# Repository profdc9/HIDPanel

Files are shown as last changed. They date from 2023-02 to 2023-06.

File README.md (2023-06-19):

# HIDPanel

This is a customizable HID controller for game panels.  The HIDPanel has positions for up to 15 plug in control modules.  These modules can be single buttons, button pairs, rotary encoders, rotary potentiometers, slide potentiometers, and dual axis joysticks (PS4 or Xbox One type replacement joysticks).

The device appears as a USB CDC serial port, a USB HID keyboard, and a USB HID gamepad.  The actions of each module is configured through the serial port.  A command string configures the Keyboard or Gamepad controls to be triggered in response to each action.

# Commands

The commands are sent via the USB CDC serial port terminated by the enter character.  Here are the commands:

SET &lt;module number&gt; &lt;action number&gt; &lt;action command string&gt;

Sets the action command string corresponding to the action number for the given module number (1 to 15).

SHOW &lt;module number&gt;

Shows the current command strings for the module number.  If the module number is zero, show the action strings for all of the modules.

WRITE

Writes the current configuration to flash memory to be restored on power up.

HELP

Display the help (the list of commands).

# Module inputs

Each module has three inputs.  Switch 1, which is a digital only input, switch 2, which is digital or analog, and an analog input, which can be used as a digital or analog input.

The action numbers are:

- 100: Button 1 Pressed (grounded)
- 101: Button 1 Released (high)
- 200: Button 2 Pressed (grounded)
- 201: Button 2 Released (high)
- 300: Analog axis pressed (grounded)
- 301: Analog axis released (high)
- 302: Analog axis moved
- 311: Analog axis position 1/9 (left most)
- 312: Analog axis position 2/9
- 313: Analog axis position 3/9
- 314: Analog axis position 4/9
- 315: Analog axis position 5/9 (center) 
- 316: Analog axis position 6/9
- 317: Analog axis position 7/9
- 318: Analog axis position 8/9
- 319: Analog axis position 9/9 (right most)
- 400: Rotary encoder left
- 401: Rotary encoder right

# Command string

The command string is a sequence of one or two character codes separated by commas.  It should not contain any spaces.  There are three modes.  The mode needs to be selected before the commands for the mode are used.  Multiple modes may be used in the command string by switching between them.  The default is keyboard mode.

- LD: LED Mode
  - Hx: Turn on LED x (x = 1 to 4)
  - Lx: Turn off LED x (x = 1 to 4)
- GP: Gamepad Mode
  - Gx: Set axis x to analog input (x = 1-6, 1=left stick x, 2=left stick y, 3=left stick z, 4=right stick x, 5=right stick y, 6=right stick z)
  - Nx: Set axis x to analog input but reverse the axis
  - Zx: Set axis x to switch 2 analog input
  - Yx: Set axis x to switch 2 analog input but reverse the axis
  - Dx: Set Dpad input to value x (x = 0-8, 0=Centered, 1=Up, 2=Up Right, 3=Right, 4=Down Right, 5=Down, 6=Down Left, 7=Left, 8=Up Left)
  - Hx: Press button x (x=1 to 32)
  - Lx: Release button x
- KB: Keyboard Mode
  - Blank (zero length): keyboard release (two consective commas).
  - LC: Select left control for next key
  - LS: Select left shift for next key
  - LA: Select left alt for next key
  - LG: Select left gui for next key
  - RC: Select right control for next key
  - RS: Select right shift for next key
  - RA: Select right alt for next key
  - RG: Select right gui for next key
  - NK: No key 
  - A-Z: Press key A to Z
  - 0-9: Press key 0 to 9
  - EN: Enter
  - ES: Escape
  - BK: Backspace
  - TB: Tab
  - SP: Space bar
  - -: Minus key
  - =: Equal key
  - [: Left bracket
  - ]: Right bracket
  - \\: Backslash
  - E1: Europe 1
  - E2: Europe 2
  - ; : Semicolon
  - ` : Grave
  - CM: Comma
  - .: Period
  - /: Slash
  - CC: Caps Lock
  - F1-F9: F1 to F9
  - FA: F10 key
  - FB: F11 key
  - FC: F12 Key
  - PS: Print Screen
  - SL: Scroll Lock
  - PA: Pause
  - IN: Insert 
  - HO: Home
  - PU: Page Up
  - DE: Delete
  - ED: End
  - PD: Page Down
  - AR: Arrow Right
  - AL: Arrow Left
  - AD: Arrow Down
  - AU: Arrow Up
  - NL: Num Lock
  - KD: Keypad Divide
  - KM: Keypad Multiple
  - KS: Keypad Subtract
  - KA: Keypad Add
  - KE: Keypad Enter
  - K0-K9: Keypad 0 to 9
  - KL: Keypad Decimal Point
  - KQ: Keypad Equal

Examples:

- KB,LS,H,,E,,L,,L,,O,, : Type the word "HELLO" with the left shift key pressed down during "H" (to capitalize it).
- GP,G2 : Take the analog value of the module and set it to the left stick Y axis.
- GP,D1,D0,D1,D0,D5,D0,D5,D0,D7,D0,D3,D0,D3,D0,H2,L2,H1,L1 : Do combination up,up,down,down,left,right,left,right (on DPad), and then press and release button 2 and then button 1.
- GP,H1,LD,H2 : press button 1, light up LED 2
- KB,F1,GP,H1,LD,L3,GP,L1 : Press keyboard key F1, press button 1 on gamepad, turn off LED 3, release button 1 on gamepad.  Button F1 remains pressed.

Complete commands:

- SET 1 100 KB,A,, : when button 1 on module 1 is pressed, press down the A key
- SET 1 101 KB,, : when button 1 on module 1 is release, release any key
- SET 11 302 GP,G1 : set analog axis of module 11 to axis 1 of the gamepad
- SET 15 302 GP,G2 : set analog axis of module 15 to axis 2 of the gamepad
- SET 11 302 GP,N1 : set analog axis of module 11 to axis 1 of the gamepad, but invert the input
- SET 15 302 GP,N2 : set analog axis of module 15 to axis 2 of the gamepad, but invert the input
- SET 11 100,GP,H4 : when analog stick button is pushed in, press button 4 on gamepad
- SET 11 101,GP,L4 : when analog stick button is released, depress button 4 on gamepad

Pictures:

The following is a pciture of the HIDPanel with different controls in it.  In module 1 is a single push button. In module 3 is a rotary potentiometer, In module 4 is a slide switch.  In module 6 is a rotary encoder.  In module 8 is a push-on push-off button.  Modules 9 and 13 have a digital gamepad.  Modules 10 and 14 have a slide potentiometer.  Modules 11 and 15 have a dual axis joystick.

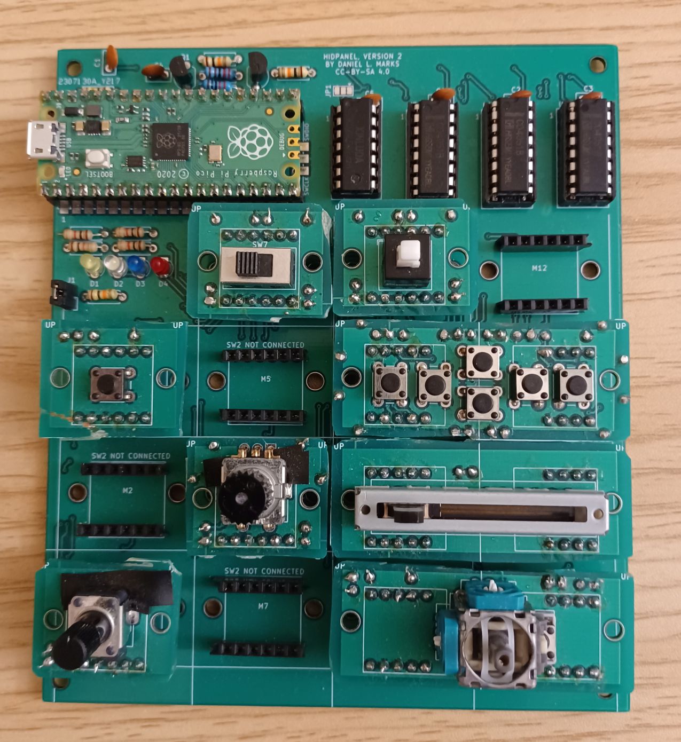
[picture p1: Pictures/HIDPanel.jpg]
HIDPanel


This is the 3-d printed cover that goes over the HIDPanel.  It is a parametric FreeCAD model and the port openings can be customized in FreeCAD before outputting the cover for the particular modules used.

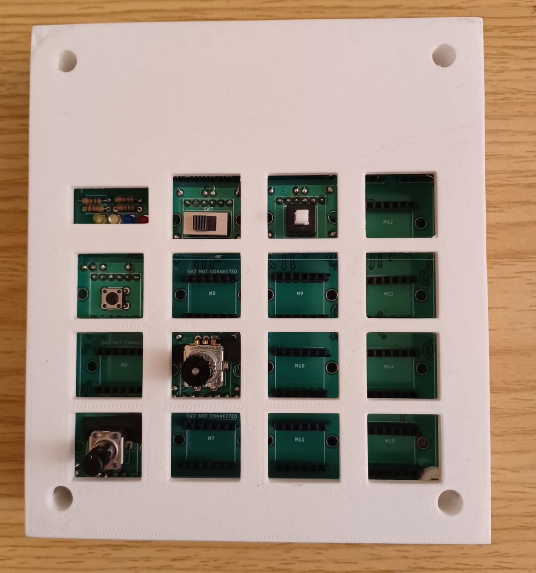
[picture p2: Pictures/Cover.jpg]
Cover


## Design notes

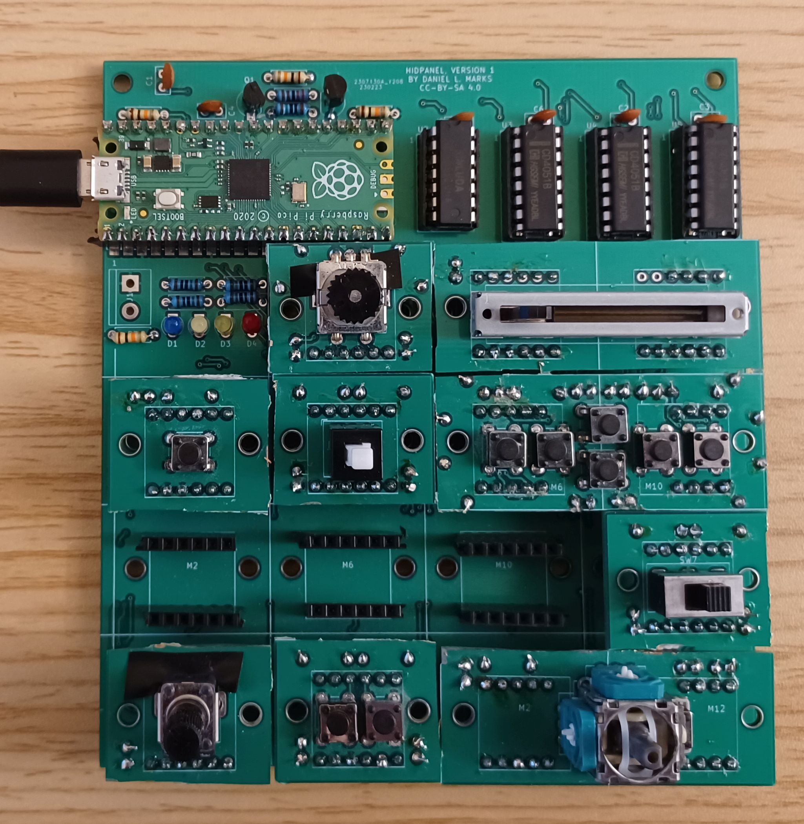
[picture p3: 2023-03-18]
Pictures/pic2.jpg

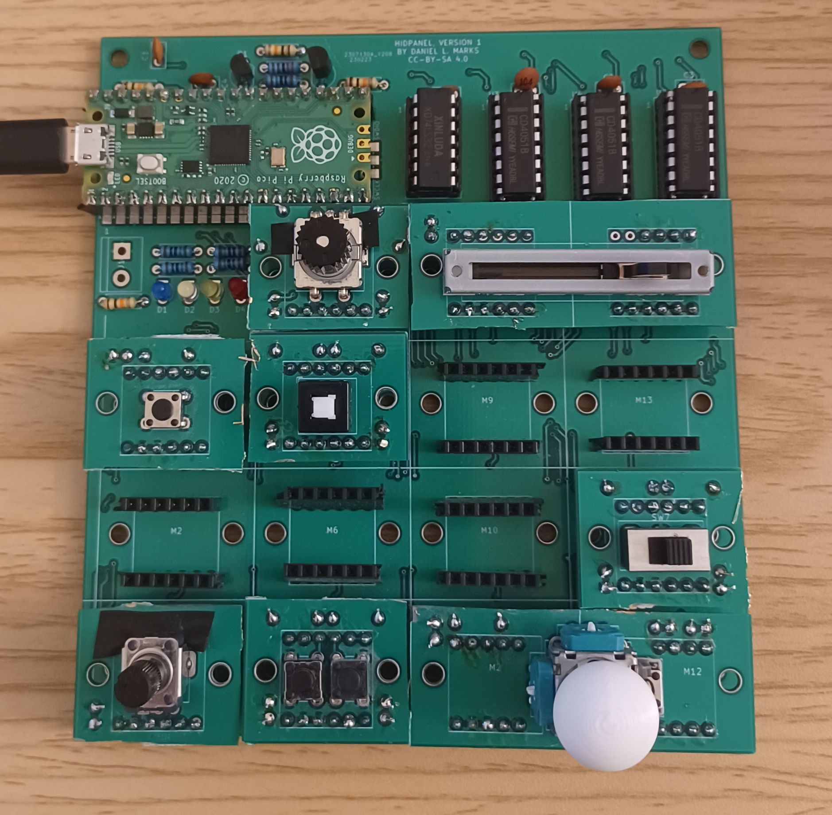
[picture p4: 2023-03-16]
Pictures/pic1.jpg

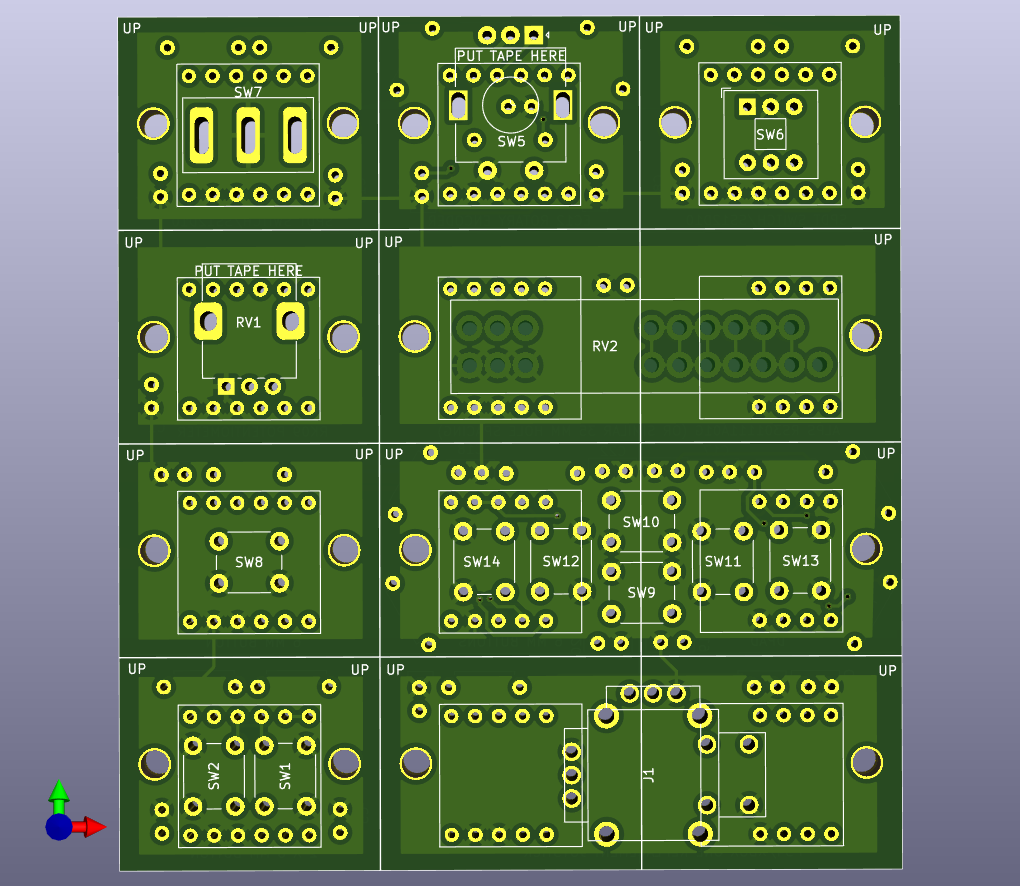
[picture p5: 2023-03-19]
HIDControls/HIDControls.png

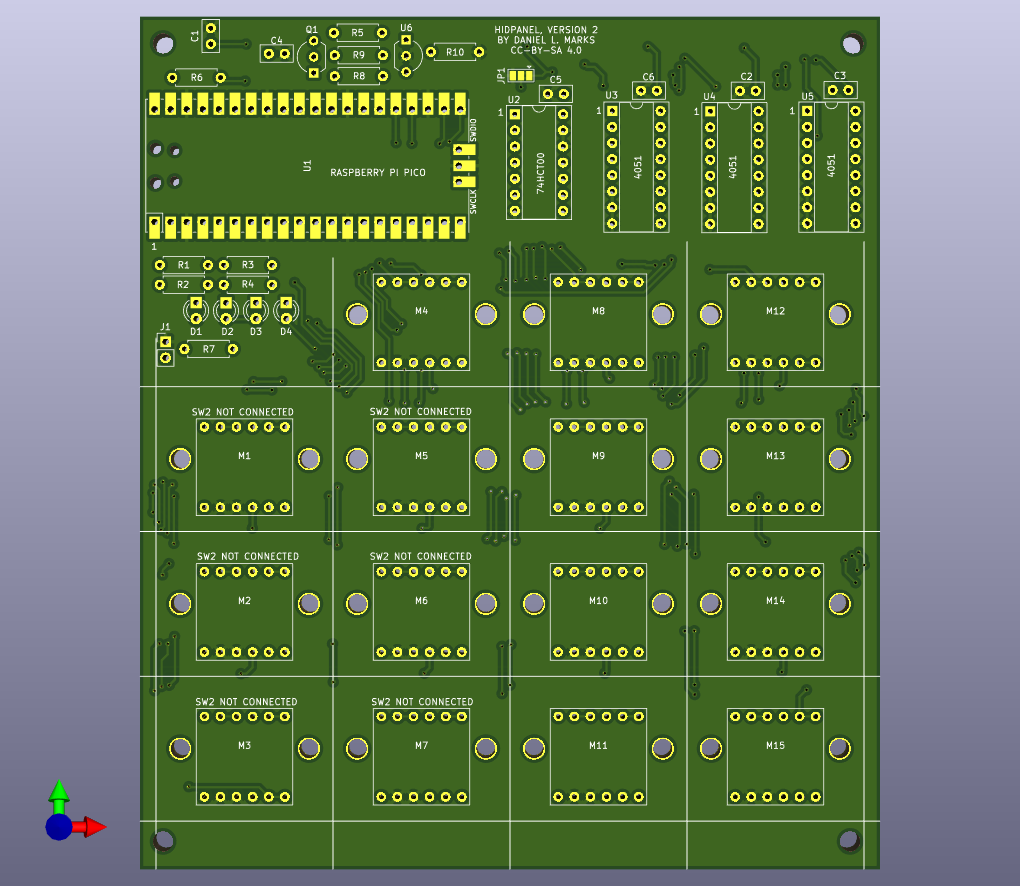
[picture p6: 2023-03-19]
HIDPanel/HIDPanel.png

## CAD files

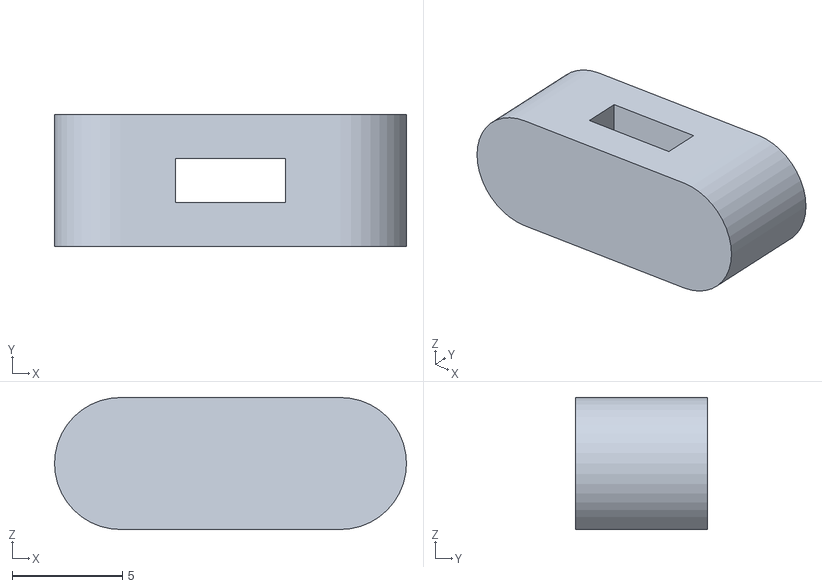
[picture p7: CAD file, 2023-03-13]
CAD/SlideLeft-SlideTotal.stl
16.0 x 6.00 x 6.00

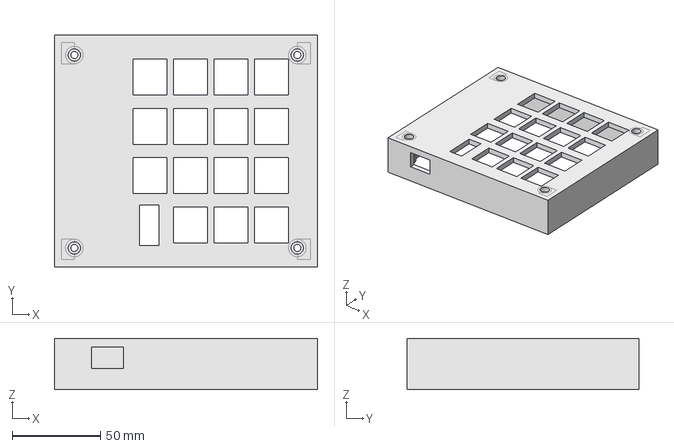
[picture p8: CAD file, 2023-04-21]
CAD/HIDPanelCover.FCStd
148.6 x 130.8 x 29.0 mm

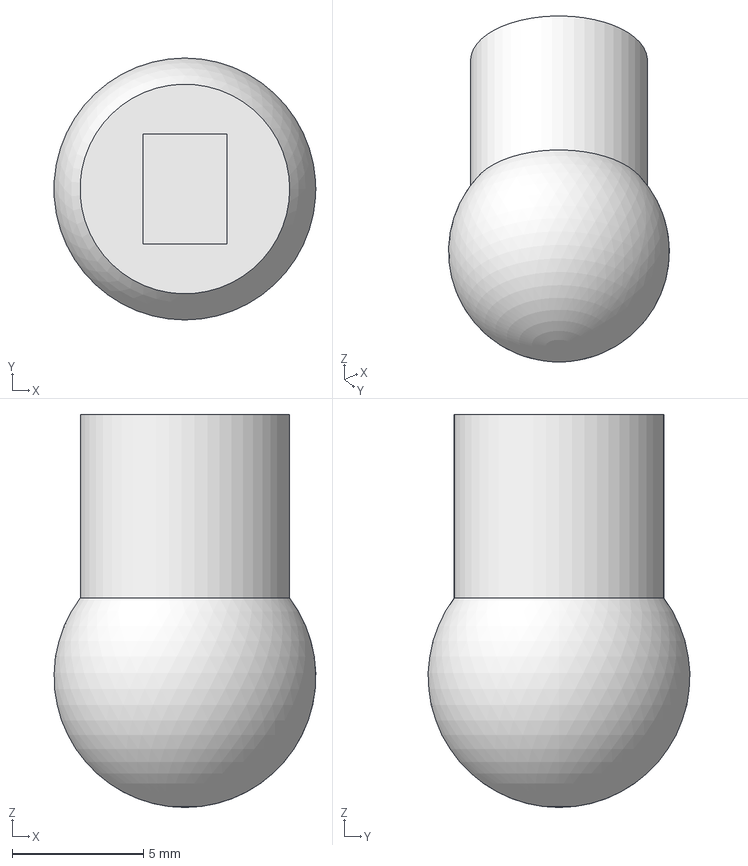
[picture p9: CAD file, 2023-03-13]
CAD/StickEnd.FCStd
9.99 x 10.00 x 15.0 mm

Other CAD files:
CAD/StickEnd-StickTotal.stl
CAD/HIDPanelCover-BoxWithStandOffs.stl
CAD/SlideLeft.FCStd

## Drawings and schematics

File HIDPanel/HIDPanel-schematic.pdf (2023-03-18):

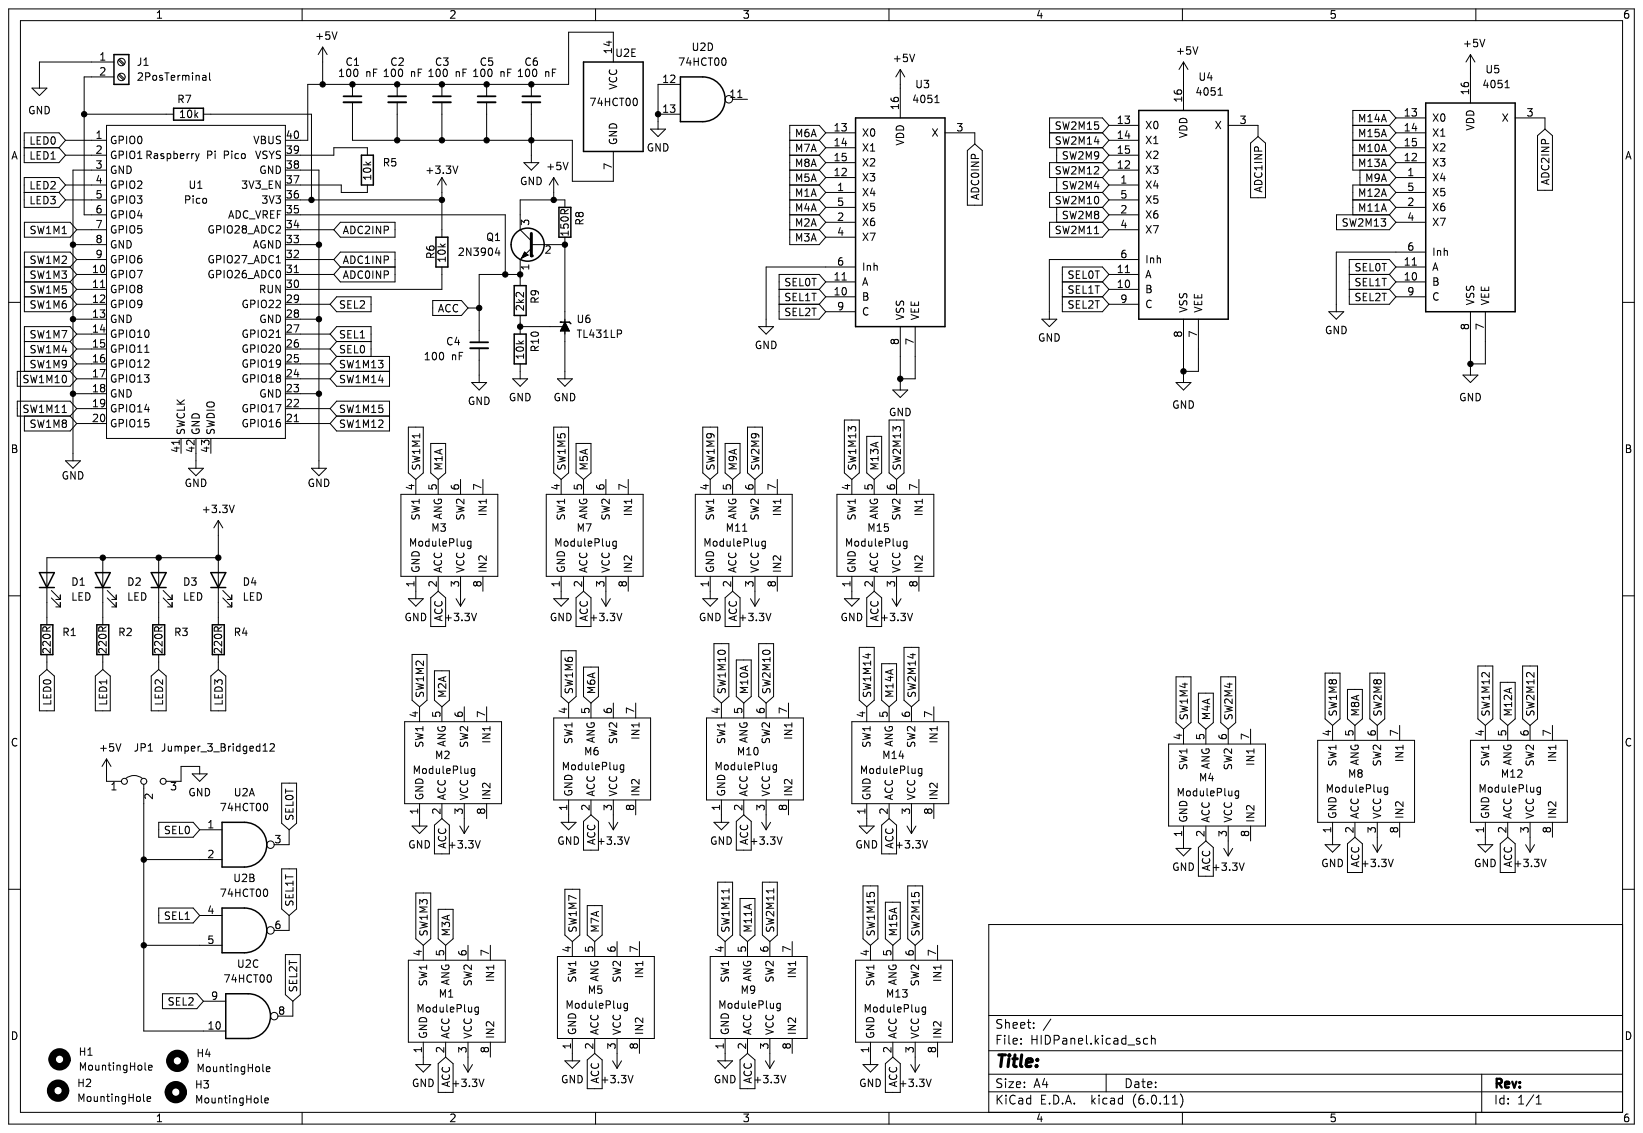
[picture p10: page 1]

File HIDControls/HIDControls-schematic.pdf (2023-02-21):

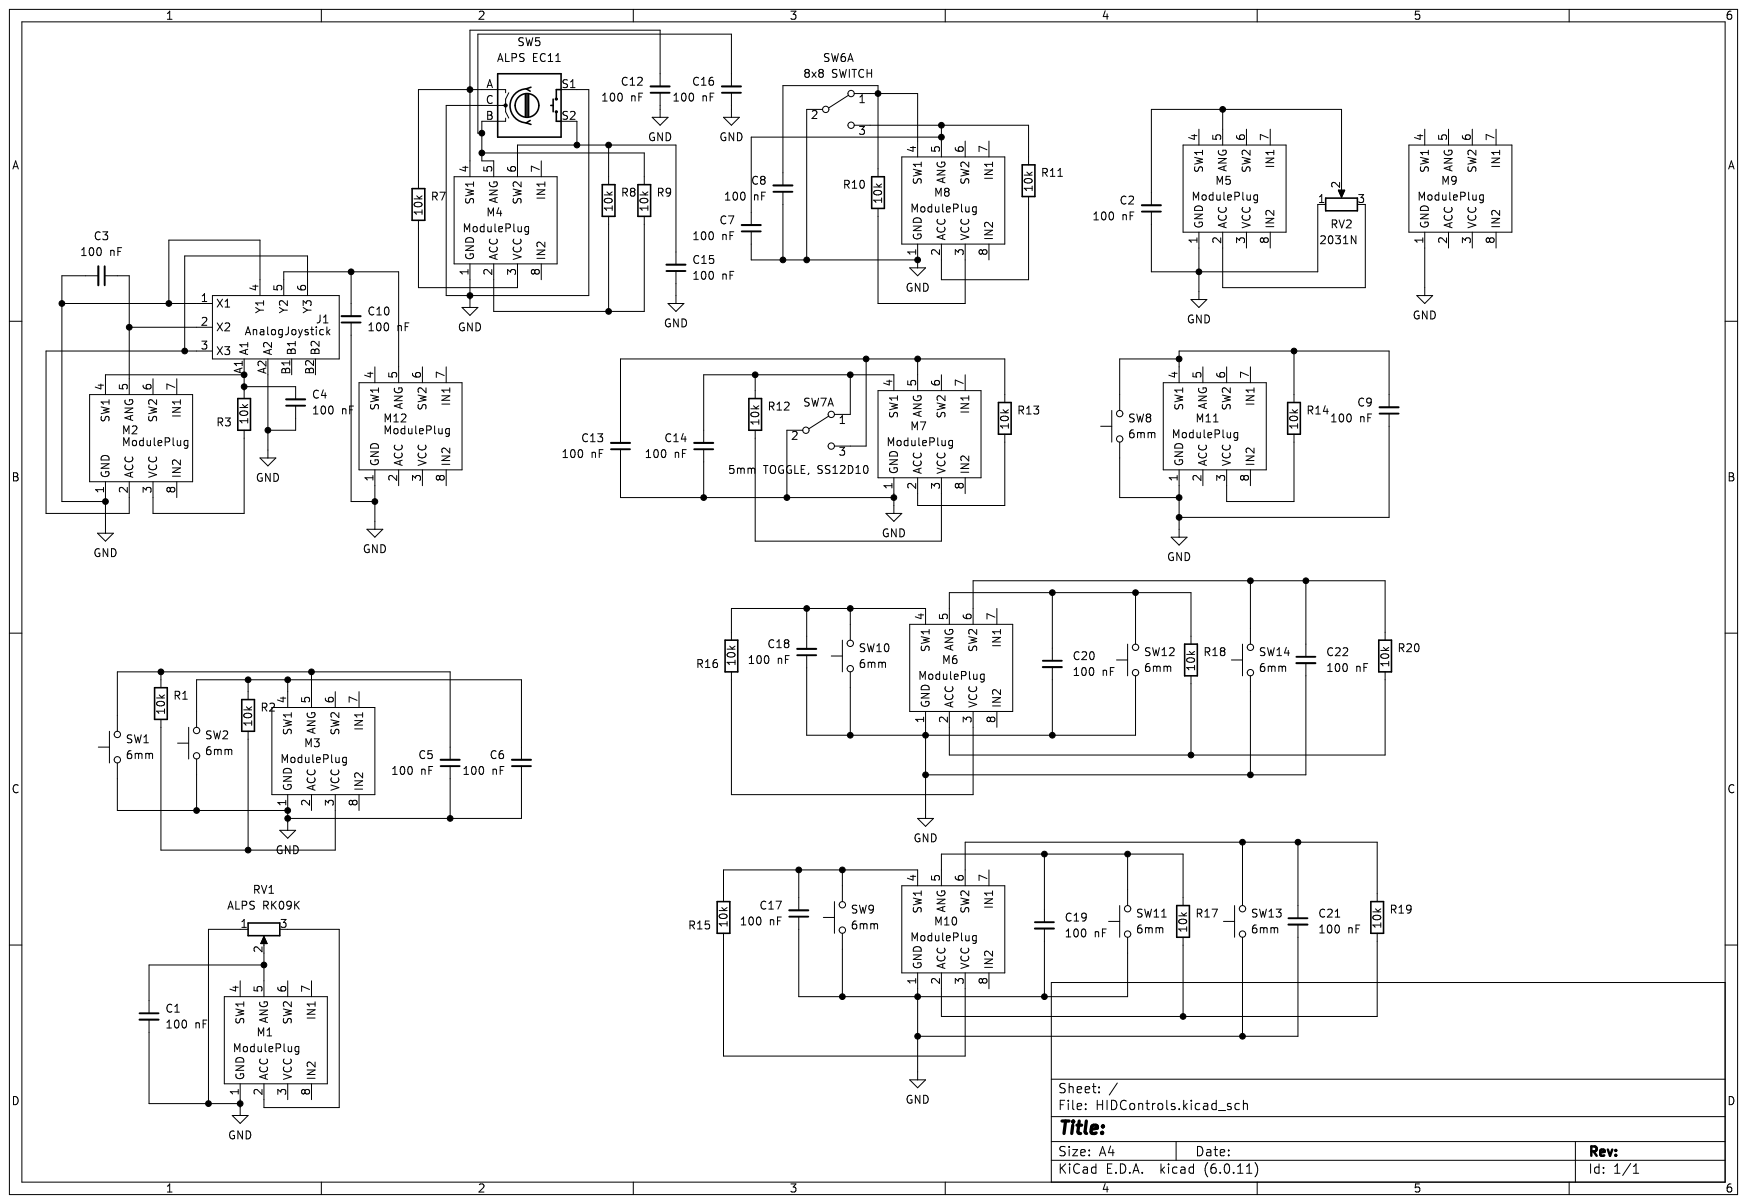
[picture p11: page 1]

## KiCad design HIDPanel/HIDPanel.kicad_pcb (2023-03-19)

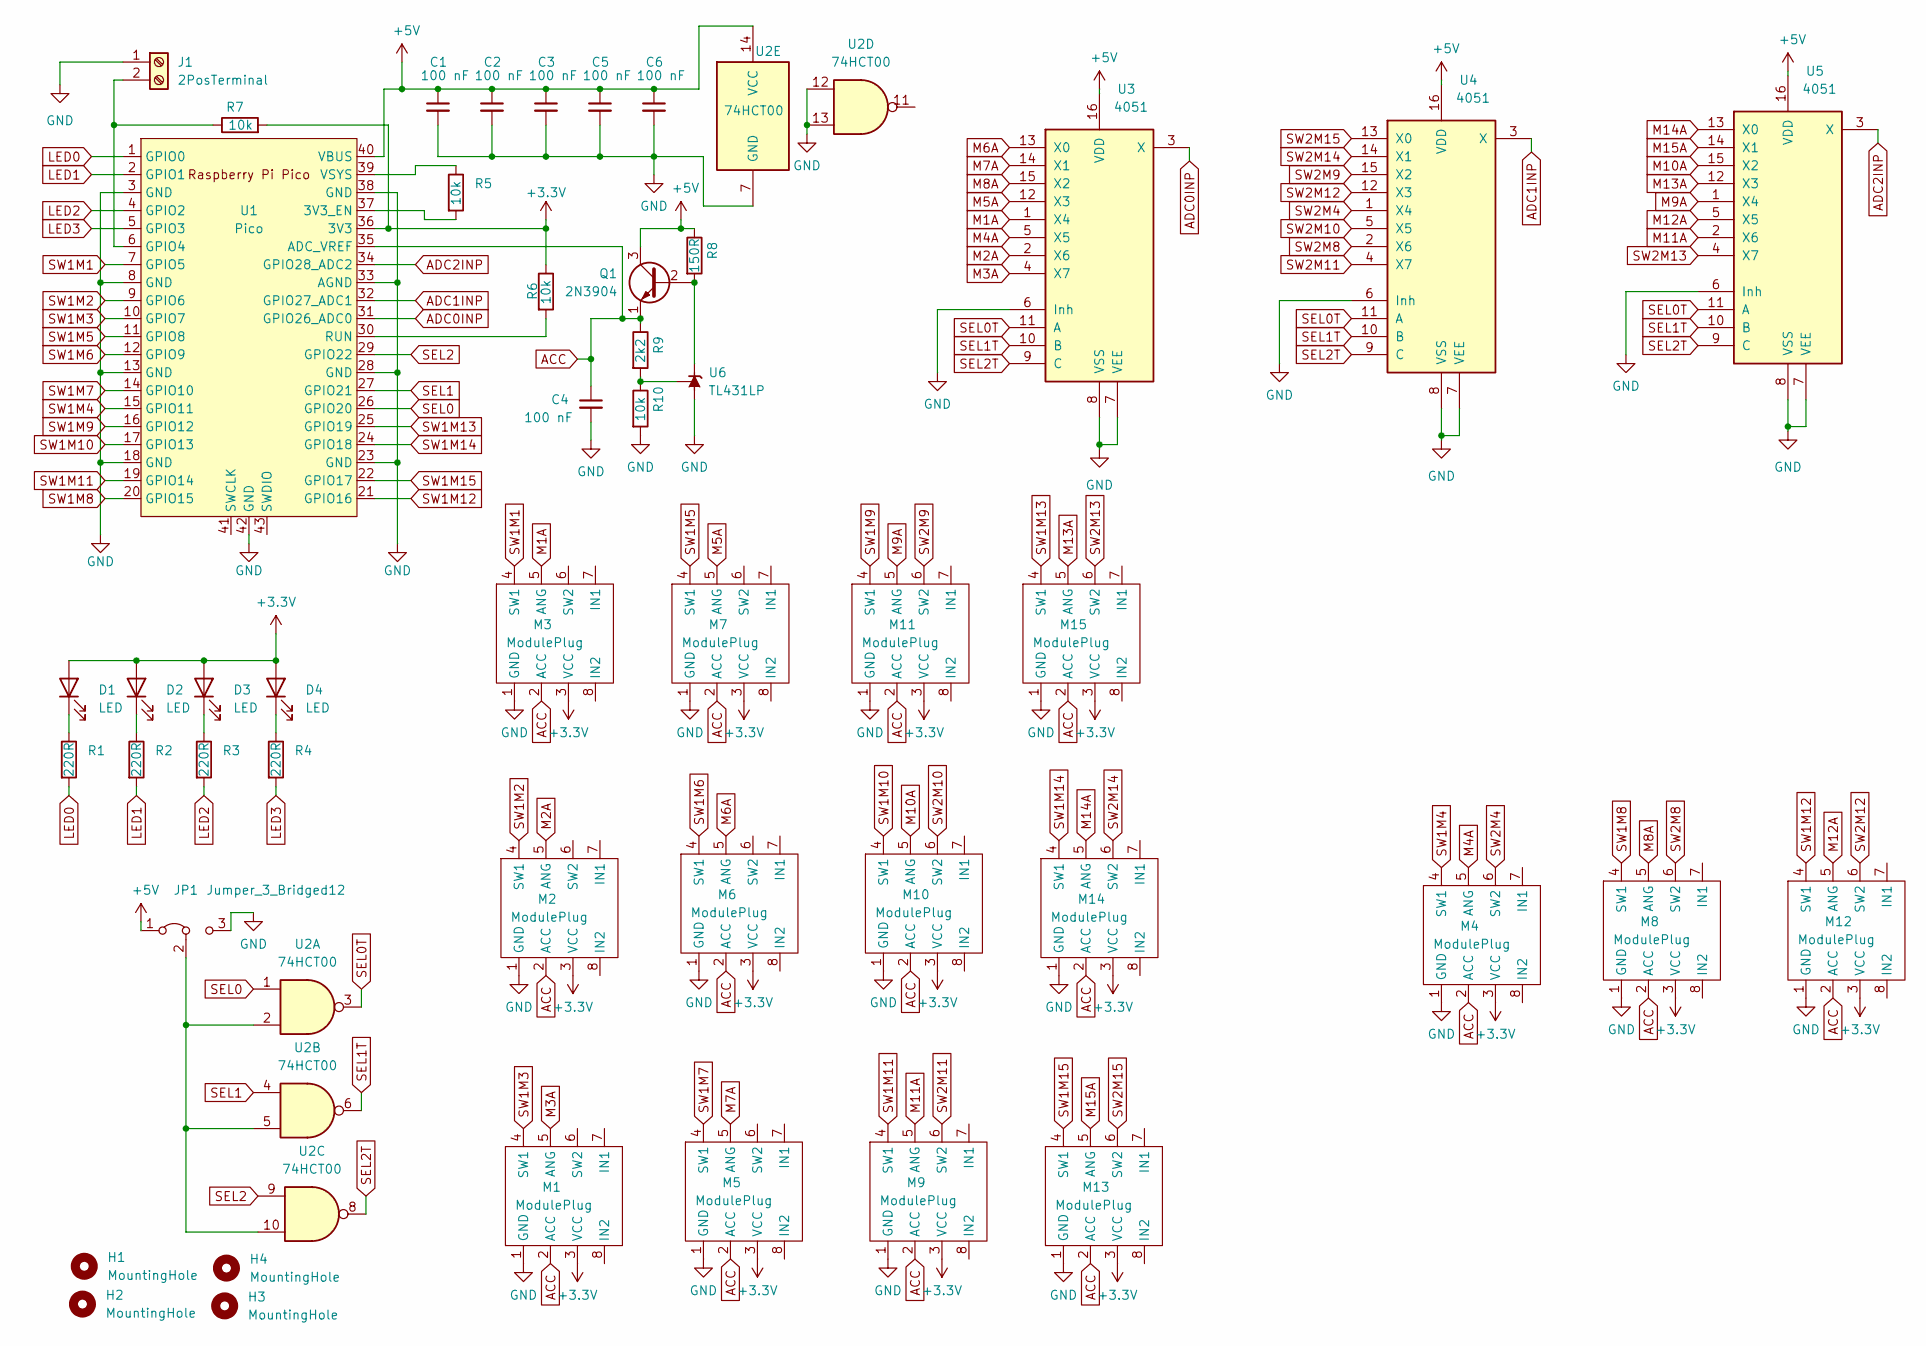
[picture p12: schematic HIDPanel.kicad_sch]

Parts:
C1, C2, C3, C4, C5, C6: 100 nF; C_Disc_D5.0mm_W2.5mm_P2.50mm
D1, D2, D3, D4: LED; LED_D3.0mm
H1, H2, H3, H4: MountingHole; MountingHole_3.2mm_M3
J1: 2PosTerminal; PinHeader_1x02_P2.54mm_Vertical
JP1: Jumper_3_Bridged12; SolderJumper-3_P1.3mm_Bridged2Bar12_Pad1.0x1.5mm
M1, M2, M3, M4, M5, M6, M7, M8, M9, M10, M11, M12, M13, M14, M15: ModulePlug
Q1: 2N3904; TO-92_Inline_Wide
R1, R2, R3, R4: 220R; R_Axial_DIN0207_L6.3mm_D2.5mm_P7.62mm_Horizontal
R5, R6, R7, R10: 10k; R_Axial_DIN0207_L6.3mm_D2.5mm_P7.62mm_Horizontal
R8: 150R; R_Axial_DIN0207_L6.3mm_D2.5mm_P7.62mm_Horizontal
R9: 2k2; R_Axial_DIN0207_L6.3mm_D2.5mm_P7.62mm_Horizontal
U1: Pico; RPi_Pico_SMD_TH
U2: 74HCT00; DIP-14_W7.62mm_Socket
U3, U4, U5: 4051; DIP-16_W7.62mm_Socket
U6: TL431LP; TO-92_Inline_Wide

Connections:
+3.3V: D1.2 (A), D2.2 (A), D3.2 (A), D4.2 (A), M1.3 (VCC), M2.3 (VCC), M3.3 (VCC), M4.3 (VCC), M5.3 (VCC), M6.3 (VCC), M7.3 (VCC), M8.3 (VCC), M9.3 (VCC), M10.3 (VCC), M11.3 (VCC), M12.3 (VCC), M13.3 (VCC), M14.3 (VCC), M15.3 (VCC), R6.1, R7.2, U1.36 (3V3)
+5V: C1.1, C2.1, C3.1, C5.1, C6.1, JP1.1 (A), Q1.3 (C), R8.1, U1.40 (VBUS), U2.14 (VCC), U3.16 (VDD), U4.16 (VDD), U5.16 (VDD)
ACC: C4.1, M1.2 (ACC), M2.2 (ACC), M3.2 (ACC), M4.2 (ACC), M5.2 (ACC), M6.2 (ACC), M7.2 (ACC), M8.2 (ACC), M9.2 (ACC), M10.2 (ACC), M11.2 (ACC), M12.2 (ACC), M13.2 (ACC), M14.2 (ACC), M15.2 (ACC), Q1.1 (E), R9.1, U1.35 (ADC_VREF)
ADC0INP: U1.31 (GPIO26_ADC0), U3.3 (X)
ADC1INP: U1.32 (GPIO27_ADC1), U4.3 (X)
ADC2INP: U1.34 (GPIO28_ADC2), U5.3 (X)
GND: C1.2, C2.2, C3.2, C4.2, C5.2, C6.2, J1.1, JP1.3 (B), M1.1 (GND), M2.1 (GND), M3.1 (GND), M4.1 (GND), M5.1 (GND), M6.1 (GND), M7.1 (GND), M8.1 (GND), M9.1 (GND), M10.1 (GND), M11.1 (GND), M12.1 (GND), M13.1 (GND), M14.1 (GND), M15.1 (GND), R10.2, U1.3 (GND), U1.8 (GND), U1.13 (GND), U1.18 (GND), U1.23 (GND), U1.28 (GND), U1.33 (AGND), U1.38 (GND), U1.42 (GND), U2.7 (GND), U2.12, U2.13, U3.6 (Inh), U3.7 (VEE), U3.8 (VSS), U4.6 (Inh), U4.7 (VEE), U4.8 (VSS), U5.6 (Inh), U5.7 (VEE), U5.8 (VSS), U6.2 (A)
LED0: R1.2, U1.1 (GPIO0)
LED1: R2.2, U1.2 (GPIO1)
LED2: R3.2, U1.4 (GPIO2)
LED3: R4.2, U1.5 (GPIO3)
M1A: M3.5 (ANG), U3.1 (X4)
M2A: M2.5 (ANG), U3.2 (X6)
M3A: M1.5 (ANG), U3.4 (X7)
M4A: M4.5 (ANG), U3.5 (X5)
M5A: M7.5 (ANG), U3.12 (X3)
M6A: M6.5 (ANG), U3.13 (X0)
M7A: M5.5 (ANG), U3.14 (X1)
M8A: M8.5 (ANG), U3.15 (X2)
M9A: M11.5 (ANG), U5.1 (X4)
M10A: M10.5 (ANG), U5.15 (X2)
M11A: M9.5 (ANG), U5.2 (X6)
M12A: M12.5 (ANG), U5.5 (X5)
M13A: M15.5 (ANG), U5.12 (X3)
M14A: M14.5 (ANG), U5.13 (X0)
M15A: M13.5 (ANG), U5.14 (X1)
unnamed: D1.1 (K), R1.1
unnamed: D2.1 (K), R2.1
unnamed: D3.1 (K), R3.1
unnamed: D4.1 (K), R4.1
unnamed: J1.2, R7.1, U1.6 (GPIO4)
unnamed: Q1.2 (B), R8.2, U6.3 (K)
unnamed: R5.1, U1.39 (VSYS)
unnamed: R5.2, U1.37 (3V3_EN)
unnamed: R6.2, U1.30 (RUN)
unnamed: R9.2, R10.1, U6.1 (REF)
unnamed: JP1.2 (C), U2.2, U2.5, U2.10
SEL0: U1.26 (GPIO20), U2.1
SEL0T: U2.3, U3.11 (A), U4.11 (A), U5.11 (A)
SEL1: U1.27 (GPIO21), U2.4
SEL1T: U2.6, U3.10 (B), U4.10 (B), U5.10 (B)
SEL2: U1.29 (GPIO22), U2.9
SEL2T: U2.8, U3.9 (C), U4.9 (C), U5.9 (C)
SW1M1: M3.4 (SW1), U1.7 (GPIO5)
SW1M2: M2.4 (SW1), U1.9 (GPIO6)
SW1M3: M1.4 (SW1), U1.10 (GPIO7)
SW1M4: M4.4 (SW1), U1.15 (GPIO11)
SW1M5: M7.4 (SW1), U1.11 (GPIO8)
SW1M6: M6.4 (SW1), U1.12 (GPIO9)
SW1M7: M5.4 (SW1), U1.14 (GPIO10)
SW1M8: M8.4 (SW1), U1.20 (GPIO15)
SW1M9: M11.4 (SW1), U1.16 (GPIO12)
SW1M10: M10.4 (SW1), U1.17 (GPIO13)
SW1M11: M9.4 (SW1), U1.19 (GPIO14)
SW1M12: M12.4 (SW1), U1.21 (GPIO16)
SW1M13: M15.4 (SW1), U1.25 (GPIO19)
SW1M14: M14.4 (SW1), U1.24 (GPIO18)
SW1M15: M13.4 (SW1), U1.22 (GPIO17)
SW2M4: M4.6 (SW2), U4.1 (X4)
SW2M8: M8.6 (SW2), U4.2 (X6)
SW2M9: M11.6 (SW2), U4.15 (X2)
SW2M10: M10.6 (SW2), U4.5 (X5)
SW2M11: M9.6 (SW2), U4.4 (X7)
SW2M12: M12.6 (SW2), U4.12 (X3)
SW2M13: M15.6 (SW2), U5.4 (X7)
SW2M14: M14.6 (SW2), U4.14 (X1)
SW2M15: M13.6 (SW2), U4.13 (X0)

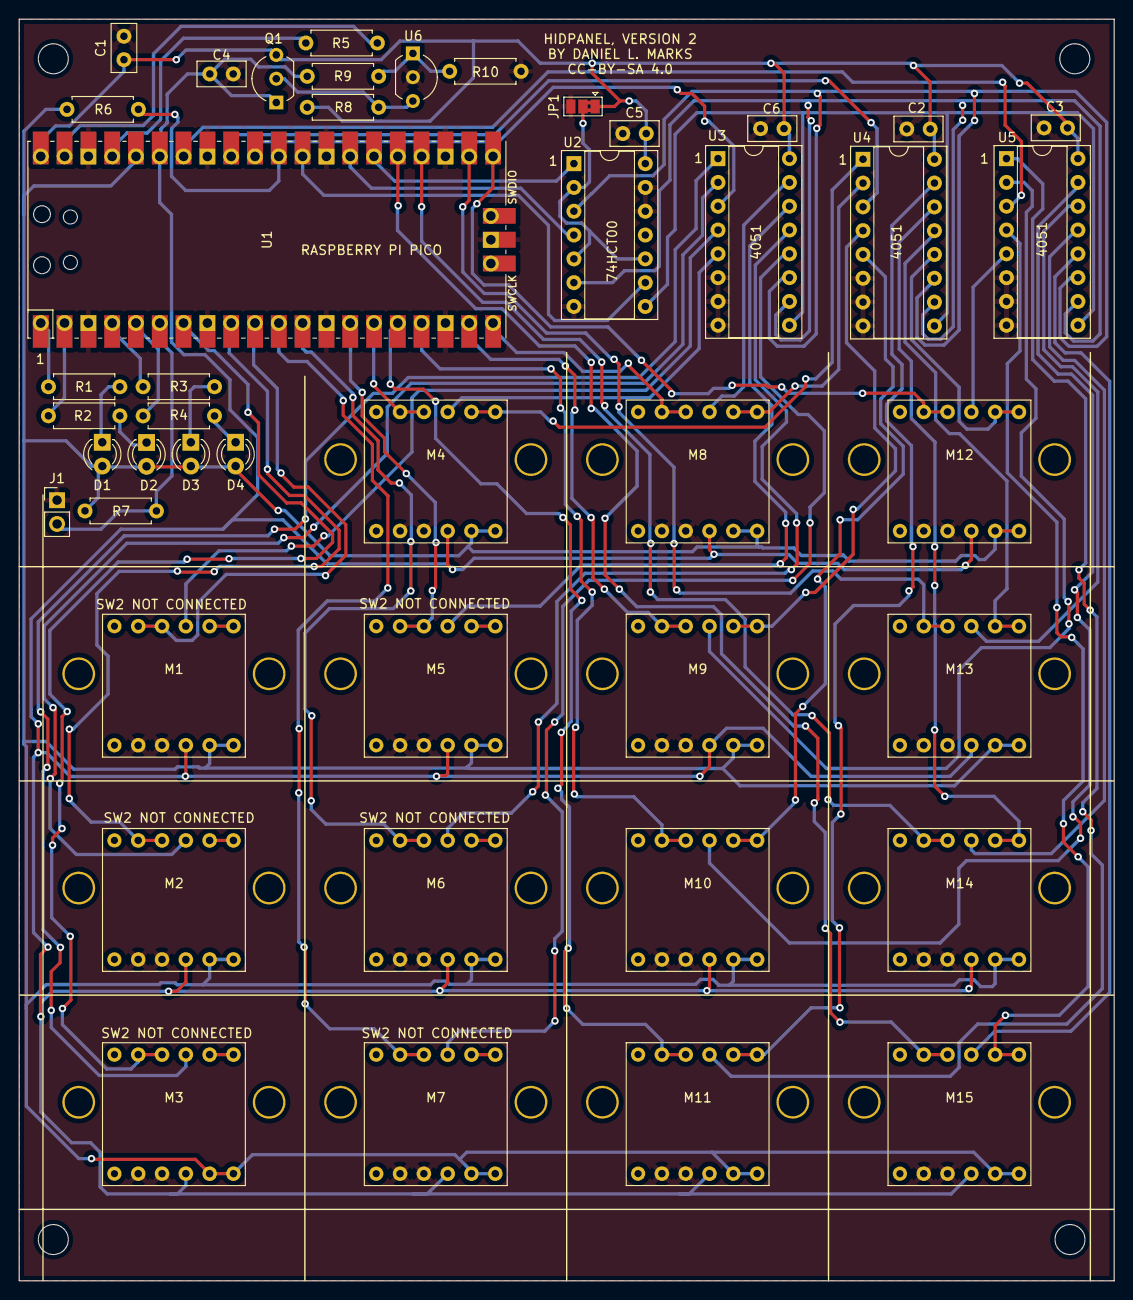
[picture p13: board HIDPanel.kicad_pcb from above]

Board: 2 copper layers, 116.8 x 134.6 mm, 48 parts (0 on the bottom side), 67 nets.

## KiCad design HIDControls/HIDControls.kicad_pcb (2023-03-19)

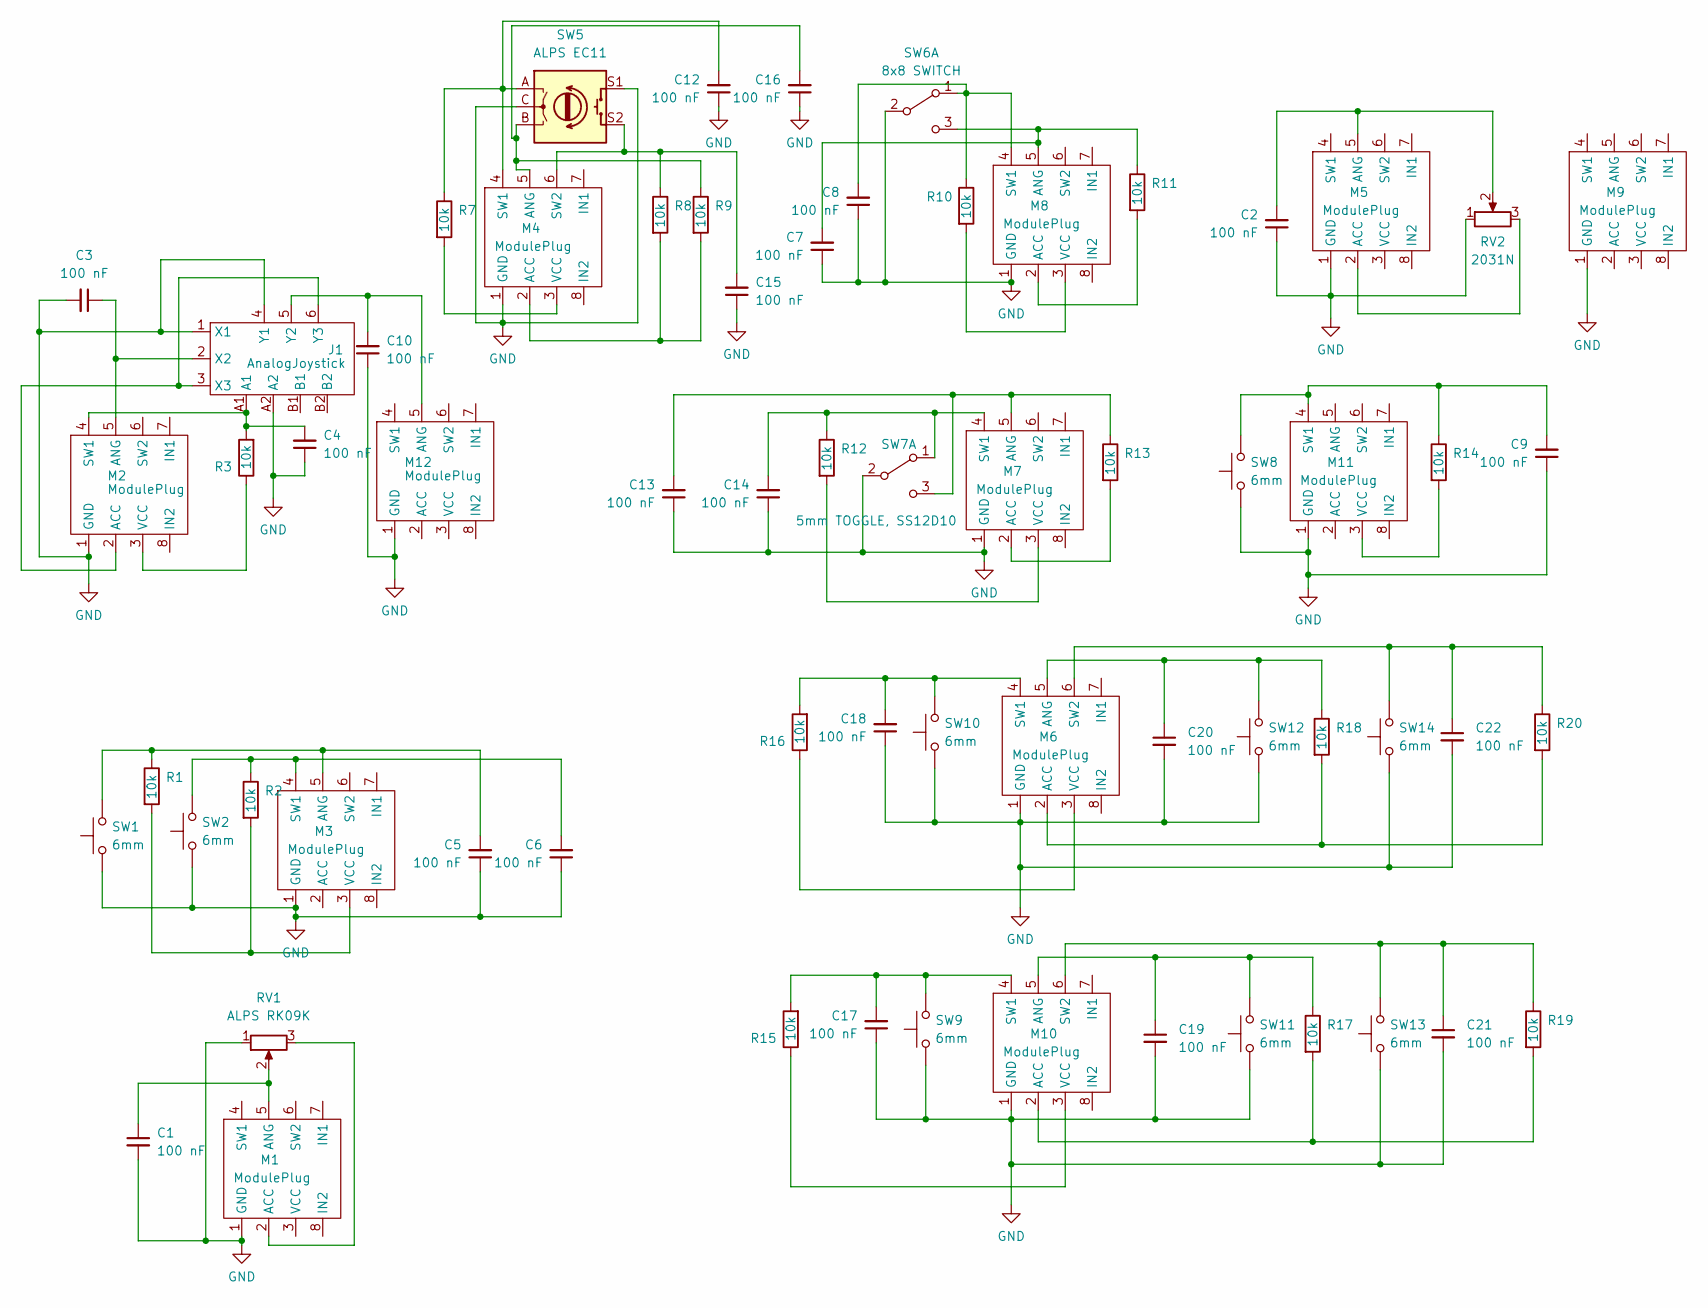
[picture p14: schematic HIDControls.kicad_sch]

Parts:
C1, C2, C3, C4, C5, C6, C7, C8, C9, C10, C12, C13, C14, C15, C16, C17, C18, C19, C20, C21, C22: 100 nF; C_Disc_D5.0mm_W2.5mm_P2.50mm
J1: AnalogJoystick
M1, M3, M4, M7, M8, M11: ModulePlug
M2, M5, M6: ModulePlug; LeftPartModulePlug
M9, M10, M12: ModulePlug; RightPartModulePlug
R1, R2, R3, R7, R8, R9, R10, R11, R12, R13, R14, R15, R16, R17, R18, R19, R20: 10k; R_Axial_DIN0207_L6.3mm_D2.5mm_P7.62mm_Horizontal
RV1: ALPS RK09K; Potentiometer_Alps_RK09K_Single_Vertical
RV2: 2031N; Linear-Pot-2031N
SW1, SW2, SW8, SW9, SW10, SW11, SW12, SW13, SW14: 6mm; SW_PUSH_6mm
SW5: ALPS EC11; RotaryEncoder_Alps_EC11E-Switch_Vertical_H20mm
SW6: 8x8 SWITCH; SW_Push_2P2T_Toggle_CK_PVA2xxH1xxxxxxV2
SW7: 5mm TOGGLE, SS12D10; 5mmSPDTtoggle

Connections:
GND: C1.2, C2.1, C3.2, C4.1, C5.1, C6.1, C7.1, C8.1, C9.1, C10.1, C12.1, C13.1, C14.1, C15.1, C16.1, C17.1, C18.1, C19.2, C20.2, C21.2, C22.2, J1.1 (X1), J1.4 (Y1), J1.A2, M1.1 (GND), M2.1 (GND), M3.1 (GND), M4.1 (GND), M5.1 (GND), M6.1 (GND), M7.1 (GND), M8.1 (GND), M9.1 (GND), M10.1 (GND), M11.1 (GND), M12.1 (GND), RV1.1, RV2.1, SW1.1, SW2.1, SW5.C, SW5.S1, SW6.2 (B), SW7.2 (B), SW8.1, SW9.1, SW10.1, SW11.1, SW12.1, SW13.1, SW14.1
unnamed: C1.1, M1.5 (ANG), RV1.2
unnamed: C2.2, M5.5 (ANG), RV2.2
unnamed: C3.1, J1.2 (X2), M2.5 (ANG)
unnamed: C4.2, J1.A1, M2.4 (SW1), R3.2
unnamed: C5.2, M3.5 (ANG), R1.1, SW1.2
unnamed: C6.2, M3.4 (SW1), R2.1, SW2.2
unnamed: C7.2, M8.5 (ANG), R11.1, SW6.3 (C)
unnamed: C8.2, M8.4 (SW1), R10.1, SW6.1 (A)
unnamed: C9.2, M11.4 (SW1), R14.1, SW8.2
unnamed: C10.2, J1.5 (Y2), M12.5 (ANG)
unnamed: C12.2, M4.4 (SW1), R7.1, SW5.A
unnamed: C13.2, M7.5 (ANG), R13.1, SW7.3 (C)
unnamed: C14.2, M7.4 (SW1), R12.1, SW7.1 (A)
unnamed: C15.2, M4.6 (SW2), R8.1, SW5.S2
unnamed: C16.2, M4.5 (ANG), R9.1, SW5.B
unnamed: C17.2, M10.4 (SW1), R15.2, SW9.2
unnamed: C18.2, M6.4 (SW1), R16.2, SW10.2
unnamed: C19.1, M10.5 (ANG), R17.1, SW11.2
unnamed: C20.1, M6.5 (ANG), R18.1, SW12.2
unnamed: C21.1, M10.6 (SW2), R19.1, SW13.2
unnamed: C22.1, M6.6 (SW2), R20.1, SW14.2
unnamed: J1.3 (X3), J1.6 (Y3), M2.2 (ACC)
unnamed: M1.2 (ACC), RV1.3
unnamed: M2.3 (VCC), R3.1
unnamed: M3.3 (VCC), R1.2, R2.2
unnamed: M4.2 (ACC), R8.2, R9.2
unnamed: M4.3 (VCC), R7.2
unnamed: M5.2 (ACC), RV2.3
unnamed: M6.2 (ACC), R18.2, R20.2
unnamed: M6.3 (VCC), R16.1
unnamed: M7.2 (ACC), R13.2
unnamed: M7.3 (VCC), R12.2
unnamed: M8.2 (ACC), R11.2
unnamed: M8.3 (VCC), R10.2
unnamed: M10.2 (ACC), R17.2, R19.2
unnamed: M10.3 (VCC), R15.1
unnamed: M11.3 (VCC), R14.2

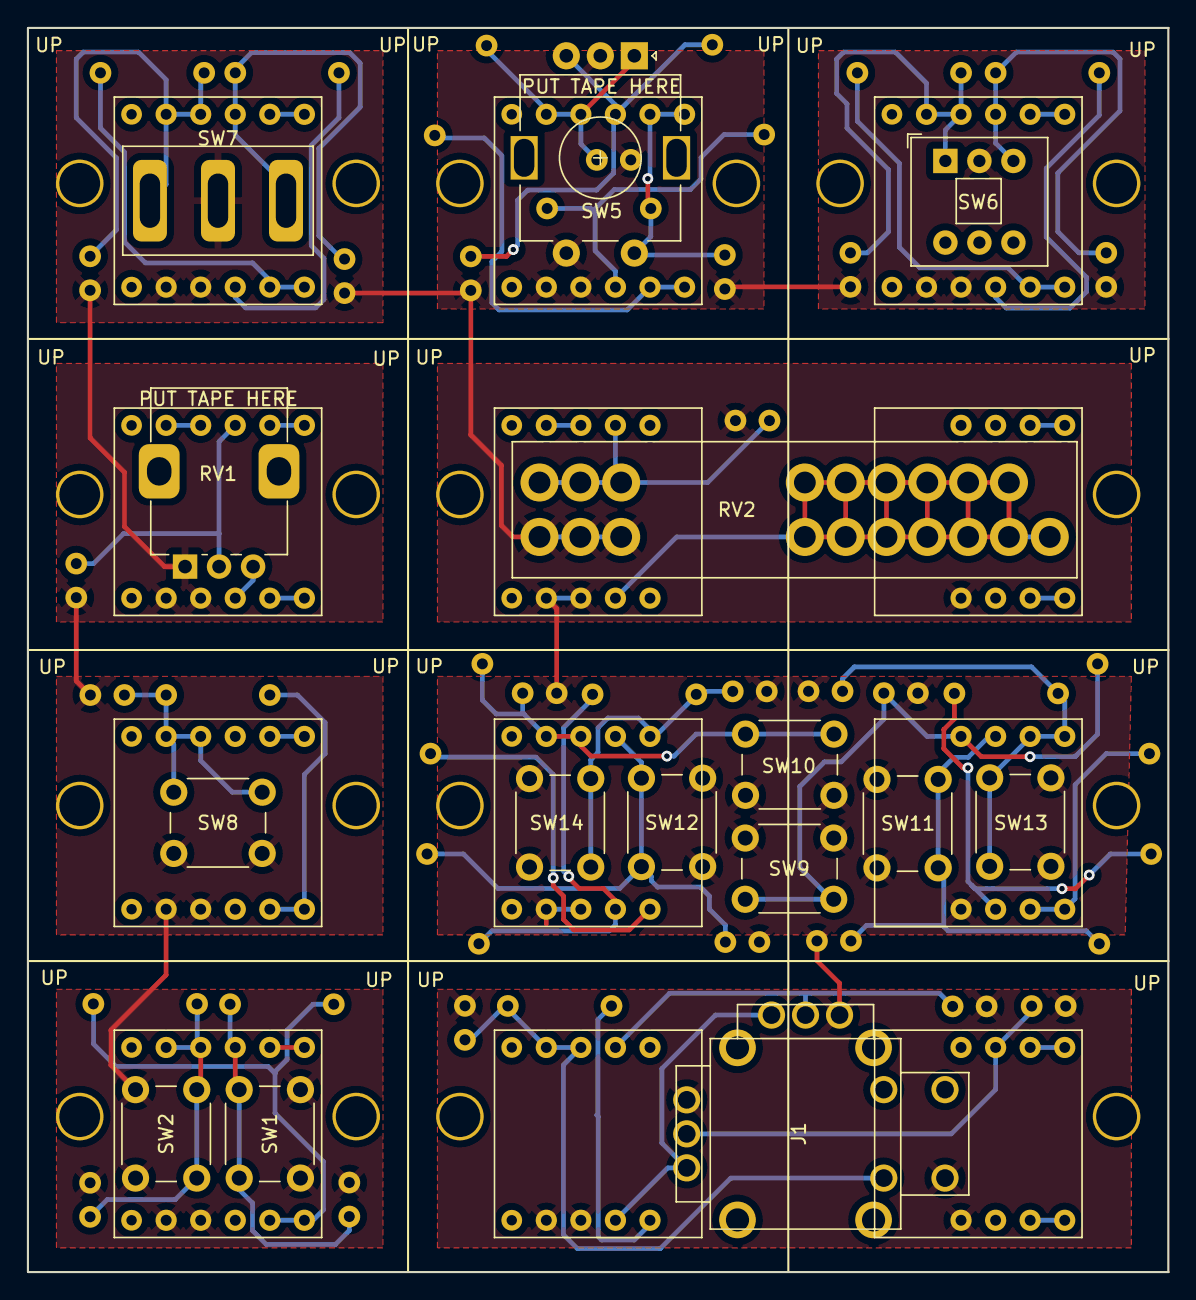
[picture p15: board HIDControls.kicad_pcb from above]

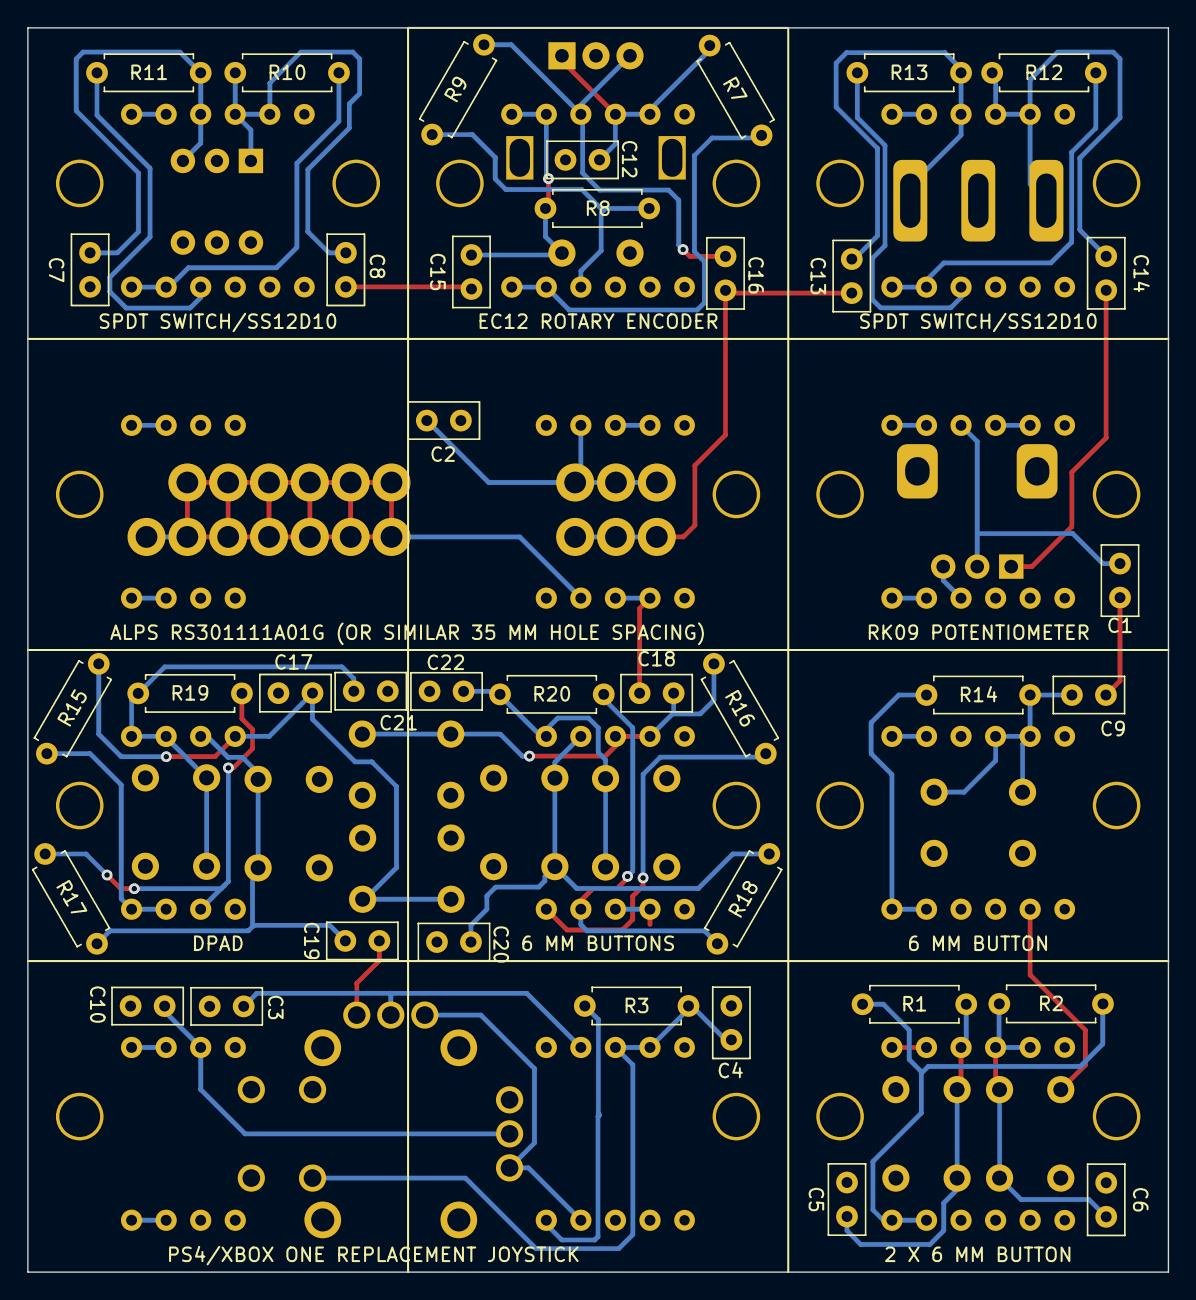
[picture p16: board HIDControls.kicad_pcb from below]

Board: 2 copper layers, 83.8 x 91.4 mm, 65 parts (38 on the bottom side), 38 nets.

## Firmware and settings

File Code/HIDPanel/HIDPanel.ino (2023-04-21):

/* HIPanel firmware */
/* by Daniel L. Marks */

/*
   Copyright (c) 2023 Daniel Marks

  This software is provided 'as-is', without any express or implied
  warranty. In no event will the authors be held liable for any damages
  arising from the use of this software.

  Permission is granted to anyone to use this software for any purpose,
  including commercial applications, and to alter it and redistribute it
  freely, subject to the following restrictions:

  1. The origin of this software must not be misrepresented; you must not
   claim that you wrote the original software. If you use this software
   in a product, an acknowledgment in the product documentation would be
   appreciated but is not required.
  2. Altered source versions must be plainly marked as such, and must not be
   misrepresented as being the original software.
  3. This notice may not be removed or altered from any source distribution.
*/

#define INPUT_SELECT_INVERTED 1

#define LED0 0
#define LED1 1
#define LED2 2
#define LED3 3

#define SEL0 20
#define SEL1 21
#define SEL2 22

#define ADC0INP A0
#define ADC1INP A1
#define ADC2INP A2

#define TIMER_INTERRUPT_DEBUG         0
#define _TIMERINTERRUPT_LOGLEVEL_     0
#define TIMER1_INTERVAL_US 1000
#include <Arduino.h>
#include <Adafruit_TinyUSB.h>
#include <LittleFS.h>

#include "consoleio.h"
#include "mini-printf.h"
#include "tinycl.h"


#define NUMBER_OF_MODULES 15
#define EVENT_STRING_LENGTH 256

typedef struct _module_events
{
  char button_1_pressed[EVENT_STRING_LENGTH];
  char button_1_released[EVENT_STRING_LENGTH];

  char button_2_pressed[EVENT_STRING_LENGTH];
  char button_2_released[EVENT_STRING_LENGTH];

  char rotary_left[EVENT_STRING_LENGTH];
  char rotary_right[EVENT_STRING_LENGTH];
  
  char axis_pressed[EVENT_STRING_LENGTH];
  char axis_released[EVENT_STRING_LENGTH];
  char axis_moved[EVENT_STRING_LENGTH];

  char axis_position_1[EVENT_STRING_LENGTH];
  char axis_position_2[EVENT_STRING_LENGTH];
  char axis_position_3[EVENT_STRING_LENGTH];
  char axis_position_4[EVENT_STRING_LENGTH];
  char axis_position_5[EVENT_STRING_LENGTH];
  char axis_position_6[EVENT_STRING_LENGTH];
  char axis_position_7[EVENT_STRING_LENGTH];
  char axis_position_8[EVENT_STRING_LENGTH];
  char axis_position_9[EVENT_STRING_LENGTH];
  
} module_events;

typedef struct _module_state
{
  uint8_t button_1_pressed;
  uint8_t button_2_pressed;
  uint8_t axis_pressed;

  uint8_t button_1_state;
  uint8_t button_1_changed;
  uint8_t button_1_count;

  uint8_t button_2_state;
  uint8_t button_2_changed;
  uint8_t button_2_count;
  int8_t  button_2_value;
  
  uint8_t axis_state;
  uint8_t axis_changed;
  int8_t  axis_value;
  uint8_t axis_count;

  int8_t last_axis_value;
  uint8_t last_axis_count;
  uint8_t axis_moved;

  uint8_t last_axis_detent;
} module_state;

module_state mod_states[NUMBER_OF_MODULES];

typedef struct _hidpanel_state
{
   uint32_t magic_number;
   module_events mod_events[NUMBER_OF_MODULES];
} hidpanel_state;

hidpanel_state hs;

LittleFSConfig littleFsConfig;

volatile uint32_t count = 0;

typedef struct _hid_key_ascii_code
{
  uint8_t hid_key_code;
  const char *ascii_code;
} hid_key_ascii_code;

const hid_key_ascii_code keycode_list[] =
{ 
  { HID_KEY_NONE, "NK" },
  { HID_KEY_A, "A" },
  { HID_KEY_B, "B" },
  { HID_KEY_C, "C" },
  { HID_KEY_D, "D" },
  { HID_KEY_E, "E" },
  { HID_KEY_F, "F" },
  { HID_KEY_G, "G" },
  { HID_KEY_H, "H" },
  { HID_KEY_I, "I" },
  { HID_KEY_J, "J" },
  { HID_KEY_K, "K" },
  { HID_KEY_L, "L" },
  { HID_KEY_M, "M" },
  { HID_KEY_N, "N" },
  { HID_KEY_O, "O" },
  { HID_KEY_P, "P" },
  { HID_KEY_Q, "Q" },
  { HID_KEY_R, "R" },
  { HID_KEY_S, "S" },
  { HID_KEY_T, "T" },
  { HID_KEY_U, "U" },
  { HID_KEY_V, "V" },
  { HID_KEY_W, "W" },
  { HID_KEY_X, "X" },
  { HID_KEY_Y, "Y" },
  { HID_KEY_Z, "Z" },
  { HID_KEY_1, "1" },
  { HID_KEY_2, "2" },
  { HID_KEY_3, "3" },
  { HID_KEY_4, "4" },
  { HID_KEY_5, "5" },
  { HID_KEY_6, "6" },
  { HID_KEY_7, "7" },
  { HID_KEY_8, "8" },
  { HID_KEY_9, "9" },
  { HID_KEY_0, "0" },
  { HID_KEY_ENTER, "EN" },
  { HID_KEY_ESCAPE, "ES" },
  { HID_KEY_BACKSPACE, "BK" },
  { HID_KEY_TAB, "TB" },
  { HID_KEY_SPACE, "SP" },
  { HID_KEY_MINUS, "-" },
  { HID_KEY_EQUAL, "=" },
  { HID_KEY_BRACKET_LEFT, "[" },
  { HID_KEY_BRACKET_RIGHT, "]" },
  { HID_KEY_BACKSLASH, "\"" },
  { HID_KEY_EUROPE_1, "E1" },
  { HID_KEY_SEMICOLON, ";" },
  { HID_KEY_APOSTROPHE, "'" },
  { HID_KEY_GRAVE, "`" },  
  { HID_KEY_COMMA, "CM" },
  { HID_KEY_PERIOD, "." },
  { HID_KEY_SLASH, "/" },
  { HID_KEY_CAPS_LOCK, "CC" },
  { HID_KEY_F1, "F1" },
  { HID_KEY_F2, "F2" },
  { HID_KEY_F3, "F3" },
  { HID_KEY_F4, "F4" },
  { HID_KEY_F5, "F5" },
  { HID_KEY_F6, "F6" },
  { HID_KEY_F7, "F7" },
  { HID_KEY_F8, "F8" },
  { HID_KEY_F9, "F9" },
  { HID_KEY_F10, "FA" },
  { HID_KEY_F11, "FB" },
  { HID_KEY_F12, "FC" },
  { HID_KEY_PRINT_SCREEN, "PS" },
  { HID_KEY_SCROLL_LOCK, "SL" },
  { HID_KEY_PAUSE, "PA" },
  { HID_KEY_INSERT, "IN" },
  { HID_KEY_HOME, "HO" },
  { HID_KEY_PAGE_UP, "PU "},
  { HID_KEY_DELETE, "DE" },
  { HID_KEY_END, "ED" },
  { HID_KEY_PAGE_DOWN, "PD" },
  { HID_KEY_ARROW_RIGHT, "AR" },
  { HID_KEY_ARROW_LEFT, "AL" },
  { HID_KEY_ARROW_DOWN, "AD" },
  { HID_KEY_ARROW_UP, "AU" },
  { HID_KEY_NUM_LOCK, "NL" },
  { HID_KEY_KEYPAD_DIVIDE, "KD" },
  { HID_KEY_KEYPAD_MULTIPLY, "KM" },
  { HID_KEY_KEYPAD_SUBTRACT, "KS" },
  { HID_KEY_KEYPAD_ADD, "KA" },
  { HID_KEY_KEYPAD_ENTER, "KE" },
  { HID_KEY_KEYPAD_1, "K1" },
  { HID_KEY_KEYPAD_2, "K2" },
  { HID_KEY_KEYPAD_3, "K3" },
  { HID_KEY_KEYPAD_4, "K4" },
  { HID_KEY_KEYPAD_5, "K5" },
  { HID_KEY_KEYPAD_6, "K6" },
  { HID_KEY_KEYPAD_7, "K7" },
  { HID_KEY_KEYPAD_8, "K8" },
  { HID_KEY_KEYPAD_9, "K9" },
  { HID_KEY_KEYPAD_0, "K0" },
  { HID_KEY_KEYPAD_DECIMAL, "KL" },
  { HID_KEY_EUROPE_2, "E2" },
  { HID_KEY_KEYPAD_EQUAL, "KQ" }
};

typedef struct _control_inputs
{
  uint8_t gpio_pin;
  uint8_t analog_select;
  uint8_t analog_adc;
  uint8_t sw2_select;
  uint8_t sw2_adc;
} control_inputs;

const control_inputs ci[] =
{
  {  7,  7, 0, 255, 255 },   // M1
  {  6,  6, 0, 255, 255 },   // M2
  {  5,  4, 0, 255, 255 },   // M3
  { 11,  5, 0,   4,   1 },   // M4 
  { 10,  1, 0, 255, 255 },   // M5
  {  9,  0, 0, 255, 255 },   // M6
  {  8,  3, 0, 255, 255 },   // M7
  { 15,  2, 0,   6,   1 },   // M8
  { 14,  6, 2,   7,   1 },   // M9
  { 13,  2, 2,   5,   1 },   // M10
  { 12,  4, 2,   2,   1 },   // M11
  { 16,  5, 2,   3,   1 },   // M12
  { 17,  1, 2,   0,   1 },   // M13
  { 18,  0, 2,   1,   1 },   // M14
  { 19,  3, 2,   4,   2 }    // M13
};

// Report ID
enum
{
  RID_KEYBOARD = 1,
  RID_GAMEPAD
};

// HID report descriptor using TinyUSB's template
uint8_t const desc_hid_report[] =
{
  TUD_HID_REPORT_DESC_KEYBOARD( HID_REPORT_ID(RID_KEYBOARD) ),
  TUD_HID_REPORT_DESC_GAMEPAD( HID_REPORT_ID(RID_GAMEPAD) )
};

// USB HID object. For ESP32 these values cannot be changed after this declaration
// desc report, desc len, protocol, interval, use out endpoint
Adafruit_USBD_HID usb_hid(desc_hid_report, sizeof(desc_hid_report), HID_ITF_PROTOCOL_NONE, 2, false);

//RPI_PICO_Timer ITimer1(1);

hid_gamepad_report_t    gp;

#define MUX_VALUES 8
#define ADC_NO 3

typedef uint8_t adc_values[MUX_VALUES][ADC_NO];

#define READ_ADC_VALUE(av,inp,adc) ( ((inp) < MUX_VALUES) ? ((*(av))[inp][adc]) : 0)

void read_mux_values(adc_values *av)
{
  for (uint8_t inp=0;inp<MUX_VALUES;inp++)
  {
#if INPUT_SELECT_INVERTED==1
    digitalWrite(SEL0, (inp & 0x01) == 0);
    digitalWrite(SEL1, (inp & 0x02) == 0);
    digitalWrite(SEL2, (inp & 0x04) == 0);
#else
    digitalWrite(SEL0, (inp & 0x01) != 0);
    digitalWrite(SEL1, (inp & 0x02) != 0);
    digitalWrite(SEL2, (inp & 0x04) != 0);
#endif
    
    for (volatile int32_t i=0;i<100;i++);
    (*av)[inp][0] = ((uint16_t)analogRead(ADC0INP)) / 256;
    (*av)[inp][1] = ((uint16_t)analogRead(ADC1INP)) / 256;
    (*av)[inp][2] = ((uint16_t)analogRead(ADC2INP)) / 256;
  }
}

void select_input(uint8_t inp)
{
#if INPUT_SELECT_INVERTED==1
  digitalWrite(SEL0, (inp & 0x01) == 0);
  digitalWrite(SEL1, (inp & 0x02) == 0);
  digitalWrite(SEL2, (inp & 0x04) == 0);
#else
  digitalWrite(SEL0, (inp & 0x01) != 0);
  digitalWrite(SEL1, (inp & 0x02) != 0);
  digitalWrite(SEL2, (inp & 0x04) != 0);
#endif
}

uint16_t read_adc(uint8_t adc)
{
   switch (adc)
   {
      case 0:  return analogRead(ADC0INP) / 256;
      case 1:  return analogRead(ADC1INP) / 256;
      case 2:  return analogRead(ADC2INP) / 256;
   }
   return 0;
}

uint16_t read_selected_adc(uint8_t inp, uint8_t adc)
{
  select_input(inp);
  for (volatile int32_t i=0;i<100;i++);
  return read_adc(adc);
}

void gamepad_clear_structure(void)
{
  memset(&gp,'\000',sizeof(gp));  
}

uint8_t gamepad_updated = 0;
uint32_t gamepad_millis_sent = 0;

void gamepad_last_sent(void)
{
  gamepad_millis_sent = millis();
  gamepad_updated = 1;
}

void gamepad_send_report(void)
{
  usb_hid.sendReport(RID_GAMEPAD, &gp, sizeof(gp));
}

#define GAMEPAD_SEND_UPDATE_TIME 2

void gamepad_send_update(void)
{
  if (gamepad_updated)
  {
    uint32_t current_time = millis();
    if ((current_time - gamepad_millis_sent) >= GAMEPAD_SEND_UPDATE_TIME)
    { 
      gamepad_send_report();      
      gamepad_updated = 0;
    }
  }  
}

void gamepad_reset_structure(void)
{
  gamepad_clear_structure();
  gamepad_send_report();
  gamepad_last_sent();
}

void gamepad_set_axis(uint8_t axis, int8_t axis_value)
{
  switch (axis)
  {
    case 1: gp.x = axis_value; break;
    case 2: gp.y = axis_value; break;
    case 3: gp.z = axis_value; break;
    case 4: gp.rx = axis_value; break;
    case 5: gp.ry = axis_value; break;
    case 6: gp.rz = axis_value; break;
  }  
  gamepad_send_report();  
  gamepad_last_sent();
}

void gamepad_set_button(uint8_t button, uint8_t state)
{
  if ((button < 1) || (button > 32)) return;
  --button;
  if (state)
    gp.buttons |= (1l << button);
  else
    gp.buttons &= ~(1l << button);
  gamepad_send_report();
  gamepad_last_sent();
}

void keyboard_send_hid_key_code(uint8_t modifier, uint8_t code)
{
    uint8_t keycode[6] = { 0 };
    keycode[0] = code;
    usb_hid.keyboardReport(RID_KEYBOARD, modifier, keycode); 
}

void set_led(uint8_t led, uint8_t state)
{
  switch (led)
  {
    case 0: digitalWrite(LED0, state); break;
    case 1: digitalWrite(LED1, state); break;
    case 2: digitalWrite(LED2, state); break;
    case 3: digitalWrite(LED3, state); break;
  }
}

typedef enum
{
  KEYBOARD_MODE = 1,
  GAMEPAD_MODE,
  LED_MODE
} command_mode;

void send_ascii_encoded_hid_codes(const char *str, int8_t axis_value, int8_t axis_value2)
{
   command_mode mode = KEYBOARD_MODE;
   uint8_t modifier = 0, prekbd = 0;
   char strcode[4];  // ascii code
   
   while (*str != 0)
   {
      uint8_t clen = 0;
      while ((*str != 0) && (*str != ',') && (clen < 3))
      {
        char c = *str++;
        if ((c >= 'a') && (c <= 'z')) c -= ' ';
        strcode[clen++] = c;
      }
      if (*str != 0) str++;
      strcode[clen] = '\000';
      
      if (strcode[0] == '!') break;
      if (!strcmp(strcode,"KB"))
      {
         modifier = 0;
         mode = KEYBOARD_MODE; continue;        
      }
      if (!strcmp(strcode,"GP"))
      {
         mode = GAMEPAD_MODE; continue;        
      }
      if (!strcmp(strcode,"LD"))
      {
        mode = LED_MODE; continue;
      }
      if (mode == LED_MODE)
      {
        if ((strcode[0] == 'H') || (strcode[0] == 'L'))
        {
          if ((strcode[1] >= '1') && (strcode[1] <= '4'))
          {
            set_led(strcode[1] - '1', strcode[0] == 'L');            
          }
        }
        continue;
      }
      if (mode == GAMEPAD_MODE)
      {
        if ((strcode[0] == 'G') && ((strcode[1] >= '1') && (strcode[1] <= '6')))
           gamepad_set_axis(strcode[1] - '1' + 1, axis_value);
        if ((strcode[0] == 'N') && ((strcode[1] >= '1') && (strcode[1] <= '6')))
           gamepad_set_axis(strcode[1] - '1' + 1, 255 - axis_value);
        if ((strcode[0] == 'Z') && ((strcode[1] >= '1') && (strcode[1] <= '6')))
           gamepad_set_axis(strcode[1] - '1' + 1, axis_value2);
        if ((strcode[0] == 'Y') && ((strcode[1] >= '1') && (strcode[1] <= '6')))
           gamepad_set_axis(strcode[1] - '1' + 1, 255 - axis_value2);
        if ((strcode[0] == 'D') || (strcode[0] == 'H') || (strcode[0] == 'L'))
        {
          if ( ((strcode[1] >= '0') && (strcode[1] <= '9')) || ((strcode[1] >= 'A') && (strcode[1] <= 'Z')) )
          {
            uint8_t axis = (strcode[1] >= 'A') ? (strcode[1] - 'A' + 10) : (strcode[1] - '0');
            if ((strcode[0] == 'D') && (axis <= 8))
            {
               gp.hat = axis;
               gamepad_send_report();                                     
               gamepad_last_sent();
               delay_idle(10);
            } else 
              gamepad_set_button(axis, strcode[0] == 'H');
              delay_idle(10);
          }
        }        
        continue;
      }
      if (mode == KEYBOARD_MODE)
      {
        if (clen == 0)
        {
          usb_hid.keyboardRelease(RID_KEYBOARD);
          modifier = 0;
          delay_idle(10);
          continue;
        }
        if (!strcmp(strcode,"LC"))
        {
          modifier |= KEYBOARD_MODIFIER_LEFTCTRL; continue;
        }
        if (!strcmp(strcode,"LS"))
        {
          modifier |= KEYBOARD_MODIFIER_LEFTSHIFT; continue;
        }
        if (!strcmp(strcode,"LA"))
        {
          modifier |= KEYBOARD_MODIFIER_LEFTALT; continue;
        }
        if (!strcmp(strcode,"LG"))
        {
          modifier |= KEYBOARD_MODIFIER_LEFTGUI; continue;
        }
        if (!strcmp(strcode,"RC"))
        {
          modifier |= KEYBOARD_MODIFIER_RIGHTCTRL; continue;
        }
        if (!strcmp(strcode,"RS"))
        {
          modifier |= KEYBOARD_MODIFIER_RIGHTSHIFT; continue;
        }
        if (!strcmp(strcode,"RA"))
        {
          modifier |= KEYBOARD_MODIFIER_RIGHTALT; continue;
        }
        if (!strcmp(strcode,"RG"))
        {
          modifier |= KEYBOARD_MODIFIER_RIGHTGUI; continue;
        }
        for (uint8_t i=0;i<(sizeof(keycode_list)/sizeof(keycode_list[0]));i++)
        {
          if (!strcmp(strcode,keycode_list[i].ascii_code))
          {
            if (!prekbd)
            {
              keyboard_send_hid_key_code(0, HID_KEY_NONE);
              delay_idle(10);
              prekbd = 1;
            }
            //Serial.println(keycode_list[i].ascii_code);           
            keyboard_send_hid_key_code(modifier, keycode_list[i].hid_key_code);
            modifier = 0;
            delay_idle(10);
            break;            
          }
        }
        continue;
      }
   }   
}

#define COUNT_CHANGED 10
#define GROUNDED_THRESHOLD -80
#define MOVED_THRESHOLD 4

void poll_modules(void)
{
  adc_values av;

  read_mux_values(&av);
  
  for (uint8_t m=0;m<NUMBER_OF_MODULES;m++)
  {
     module_state *ms = &mod_states[m];
     const control_inputs *cci = &ci[m];

     ms->button_1_pressed = !digitalRead(cci->gpio_pin);
     if (ms->button_1_pressed == ms->button_1_state)              
     {
       ms->button_1_count = 0;       
     } else
     {
       ms->button_1_count++;
       if (ms->button_1_count > COUNT_CHANGED)
       {
          if (!ms->button_1_changed)
          {
            ms->button_1_count = 0;
            ms->button_1_state = ms->button_1_pressed;
            ms->button_1_changed = 1;
          }
       }
     }

     //state = read_selected_adc(cci->sw2_select, cci->sw2_adc);
     ms->button_2_value = ((int8_t)READ_ADC_VALUE(&av,cci->sw2_select, cci->sw2_adc)) - 128;
     ms->button_2_pressed = ms->button_2_value < GROUNDED_THRESHOLD;
     if (ms->button_2_pressed == ms->button_2_state)              
     {
       ms->button_2_count = 0;       
     } else
     {
       ms->button_2_count++;
       if (ms->button_2_count > COUNT_CHANGED)
       {
         if (!ms->button_2_changed)
         {
            ms->button_2_count = 0;
            ms->button_2_state = ms->button_2_pressed;
            ms->button_2_changed = 1;
         }
       }
     }

     //state = read_selected_adc(cci->analog_select, cci->analog_adc);
     ms->axis_value = ((int8_t)READ_ADC_VALUE(&av,cci->analog_select, cci->analog_adc)) - 128;
     ms->axis_pressed = ms->axis_value < GROUNDED_THRESHOLD;
     if (ms->axis_pressed == ms->axis_state)              
     {
       ms->axis_count = 0;       
     } else
     {
       ms->axis_count++;
       if (ms->axis_count > COUNT_CHANGED)
       {
         if (!ms->axis_changed)
         {
            ms->axis_count = 0;
            ms->axis_state = ms->axis_pressed;
            ms->axis_changed = 1;
         }
       }
     }
     
     int8_t dif = ms->axis_value - ms->last_axis_value;
     if ((dif < (-MOVED_THRESHOLD)) || (dif > MOVED_THRESHOLD))
     {
       if (!ms->axis_moved)
       {
          ms->last_axis_value = ms->axis_value;              
          ms->axis_moved = 1; 
       }
     }
  }
}

void perform_actions(void)
{
  for (uint8_t m=0;m<NUMBER_OF_MODULES;m++)
  {
     module_state *ms = &mod_states[m];
     module_events *me = &hs.mod_events[m];

     if (ms->button_1_changed)
     {       
       if (ms->button_1_state)
          send_ascii_encoded_hid_codes(me->button_1_pressed, ms->axis_value, ms->button_2_value);
       else
       {
          send_ascii_encoded_hid_codes(me->button_1_released, ms->axis_value, ms->button_2_value);
          if (ms->axis_state)
            send_ascii_encoded_hid_codes(me->rotary_left, ms->axis_value, ms->button_2_value);
          else
            send_ascii_encoded_hid_codes(me->rotary_right, ms->axis_value, ms->button_2_value);
       }
       ms->button_1_changed = 0;       
     }
     if (ms->button_2_changed)
     {       
       if (ms->button_2_state)
          send_ascii_encoded_hid_codes(me->button_2_pressed, ms->axis_value, ms->button_2_value);
       else
          send_ascii_encoded_hid_codes(me->button_2_released, ms->axis_value, ms->button_2_value);
       ms->button_2_changed = 0;
     }
     if (ms->axis_changed)
     {       
       if (ms->axis_state)
          send_ascii_encoded_hid_codes(me->axis_pressed, ms->axis_value, ms->button_2_value);
       else
          send_ascii_encoded_hid_codes(me->axis_released, ms->axis_value, ms->button_2_value);
       ms->axis_changed = 0;
     }
     if (ms->axis_moved)
     {
        uint8_t av = (((int16_t)ms->axis_value) + 176) / 32;
        send_ascii_encoded_hid_codes(me->axis_moved, ms->axis_value, ms->button_2_value);
        if (av != ms->last_axis_detent)
        {
          ms->last_axis_detent = av;
          switch (av)
          {
            case 1: send_ascii_encoded_hid_codes(me->axis_position_1, ms->axis_value, ms->button_2_value); break;
            case 2: send_ascii_encoded_hid_codes(me->axis_position_2, ms->axis_value, ms->button_2_value); break;
            case 3: send_ascii_encoded_hid_codes(me->axis_position_3, ms->axis_value, ms->button_2_value); break;
            case 4: send_ascii_encoded_hid_codes(me->axis_position_4, ms->axis_value, ms->button_2_value); break;
            case 5: send_ascii_encoded_hid_codes(me->axis_position_5, ms->axis_value, ms->button_2_value); break;
            case 6: send_ascii_encoded_hid_codes(me->axis_position_6, ms->axis_value, ms->button_2_value); break;
            case 7: send_ascii_encoded_hid_codes(me->axis_position_7, ms->axis_value, ms->button_2_value); break;
            case 8: send_ascii_encoded_hid_codes(me->axis_position_8, ms->axis_value, ms->button_2_value); break;
            case 9: send_ascii_encoded_hid_codes(me->axis_position_9, ms->axis_value, ms->button_2_value); break;
          }
        }
        ms->axis_moved = 0;       
     }
  }
}

#if 0
bool TimerHandler1(struct repeating_timer *t)
{
  count++;
  return true;
}
#endif

#define MAGIC_NUMBER 0xABCFFCBA

void clearConfig(void)
{
  memset(&hs,'\000',sizeof(hs));  
  hs.magic_number = MAGIC_NUMBER;
}

uint8_t readConfig(void)
{
  clearConfig();
  File f = LittleFS.open("/config.bin","r");
  if (f)
  {
    f.read((uint8_t *)&hs,sizeof(hs));
    if (hs.magic_number != MAGIC_NUMBER)
      clearConfig();
    f.close();
    return 1;
  }
  return 0;
}

uint8_t writeConfig(void)
{
  File f = LittleFS.open("/config.bin","w");
  if (f)
  {
    f.write((uint8_t *)&hs,sizeof(hs));
    f.close();
    return 1;
  }
  return 0;
}

void setup() {
   usb_hid.begin();
   Serial.begin(9600);
   console_setMainSerial(&Serial);
   pinMode(SEL0, OUTPUT);
   pinMode(SEL1, OUTPUT);
   pinMode(SEL2, OUTPUT);
   pinMode(LED0, OUTPUT);
   pinMode(LED1, OUTPUT);
   pinMode(LED2, OUTPUT);
   pinMode(LED3, OUTPUT);
   pinMode(ADC0INP, INPUT);
   pinMode(ADC1INP, INPUT);
   pinMode(ADC2INP, INPUT);
   for (uint8_t i=5;i<20;i++) pinMode(i, INPUT);
   analogReadResolution(16);
   digitalWrite(LED0, HIGH);
   digitalWrite(LED1, HIGH);
   digitalWrite(LED2, HIGH);
   digitalWrite(LED3, HIGH);
 
   littleFsConfig.setAutoFormat(true);
   LittleFS.setConfig(littleFsConfig);
   LittleFS.begin();
   readConfig();
  
   //ITimer1.attachInterruptInterval(TIMER1_INTERVAL_US, TimerHandler1);

  // wait until device mounted
  while( !TinyUSBDevice.mounted() ) delay(1);
  gamepad_reset_structure();
}
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
void loop() {
  idle_task();
  perform_actions();
  gamepad_send_update();
  if (tinycl_task(sizeof(tcmds) / sizeof(tinycl_command), tcmds, NULL))
  {
    tinycl_do_echo = 1;
    console_print("> ");
  }

#if 0
  if ( TinyUSBDevice.suspended() && btn_pressed )
  {
    // Wake up host if we are in suspend mode
    // and REMOTE_WAKEUP feature is enabled by host
    TinyUSBDevice.remoteWakeup();
  }
#endif
}

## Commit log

2023-02-20 Tweaked some distances
    [HIDPanel-B_Cu.gbr, HIDPanel-B_Mask.gbr, HIDPanel-B_Paste.gbr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]
2023-02-20 Spaced out plugin footprint bigger
    [HIDPanel-B_Cu.gbr, HIDPanel-B_Mask.gbr, HIDPanel-B_Paste.gbr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]
2023-02-20 Added HIDControls
    [HIDControls-B_Cu.gbr, HIDControls-B_Mask.gbr, HIDControls-B_Paste.gbr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]
2023-02-21 Minor layout tweaks
    [HIDControls-B_Cu.gbr, HIDControls-B_Mask.gbr, HIDControls-B_Paste.gbr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]
2023-02-21 Added AnalogJoystick
    [HIDControls-B_Cu.gbr, HIDControls-B_Mask.gbr, HIDControls-B_Paste.gbr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]
2023-02-21 Added analog joystick device
    [HIDControls-B_Cu.gbr, HIDControls-B_Mask.gbr, HIDControls-B_Paste.gbr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]
2023-02-22 JLCPCB order 2023-22-02
    [HIDControls-B_Cu.gbr, HIDControls-B_Mask.gbr, HIDControls-B_Paste.gbr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]
2023-02-22 Oops 74HCT32 not 74HCT08
    [HIDPanel-B_Cu.gbr, HIDPanel-B_Mask.gbr, HIDPanel-B_Paste.gbr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]
2023-02-23 Added CAD cover
    [HIDPanelCover-BoxWithStandOffs.stl, HIDPanelCover.FCStd]
2023-02-26 Created example CDC,HID Keyboard,HID Gamepad device
2023-02-26 Added timer interrupt
2023-03-13 Added CAD models
    [HIDControls-B_Cu.gbr, HIDControls-B_Mask.gbr, HIDControls-B_Paste.gbr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]
2023-03-16 Working buttons, encoders
    [HIDControls-B_Cu.gbr, HIDControls-B_Mask.gbr, HIDControls-B_Paste.gbr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]
2023-03-16 Remove RPi Timers (not needed)
2023-03-18 Rev 2 HIDPanel board
    [HIDPanel-B_Cu.gbr, HIDPanel-B_Mask.gbr, HIDPanel-B_Paste.gbr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]
2023-03-18 Modified HIDControls to include labels of parts
    [HIDControls-B_Cu.gbr, HIDControls-B_Mask.gbr, HIDControls-B_Paste.gbr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]
2023-03-18 Separate fills for each control
    [HIDControls-B_Cu.gbr, HIDControls-B_Mask.gbr, HIDControls-B_Paste.gbr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]
2023-03-19 A few layout tweaks
    [HIDControls-B_Cu.gbr, HIDControls-B_Mask.gbr, HIDControls-B_Paste.gbr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]
2023-04-21 Added reinforcement for standoffs
    [HIDPanelCover-BoxWithStandOffs.stl, HIDPanelCover.FCStd]

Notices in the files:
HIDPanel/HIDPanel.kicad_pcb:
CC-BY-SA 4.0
